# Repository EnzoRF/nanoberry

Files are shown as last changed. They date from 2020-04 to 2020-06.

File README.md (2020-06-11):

# Project Nanoberry*
(*) Provisional name until we find anything better

# What is it?
Nanoberry is a **single-board computer** capable of running **Linux**. It is built around the **i. MX 6 UltraLite** system-on-chip from NXP. It's **open-source hardware**, its design files are made in **KiCad** and it's free for everyone to produce it, sell it, modify it, and sell modified versions of it.

It is designed to be similar to the very popular **Raspberry PI**, with the same board size and connectors located in the same side. There are some differences, most notably it does not have HDMI output.

The goal is to have a small computer that everybody can modify according to their needs. All the electronics components can be purchased from electronics distributors and its operation is well documented by the manufacturers. This is the main difference with Raspberry PI.

All components are also available in industrial grade, for projects that require extra reliabilty with an increase in the cost. 

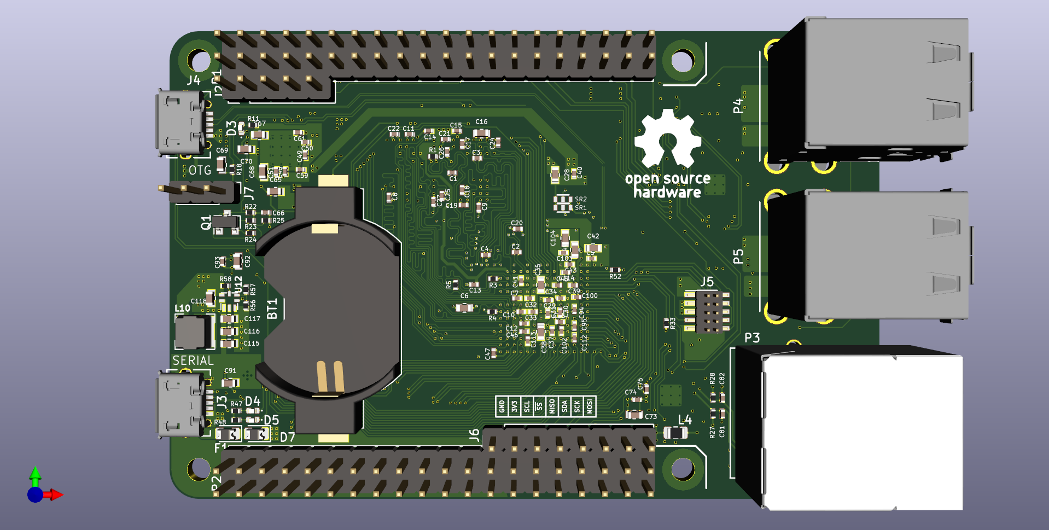
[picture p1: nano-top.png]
3d model front


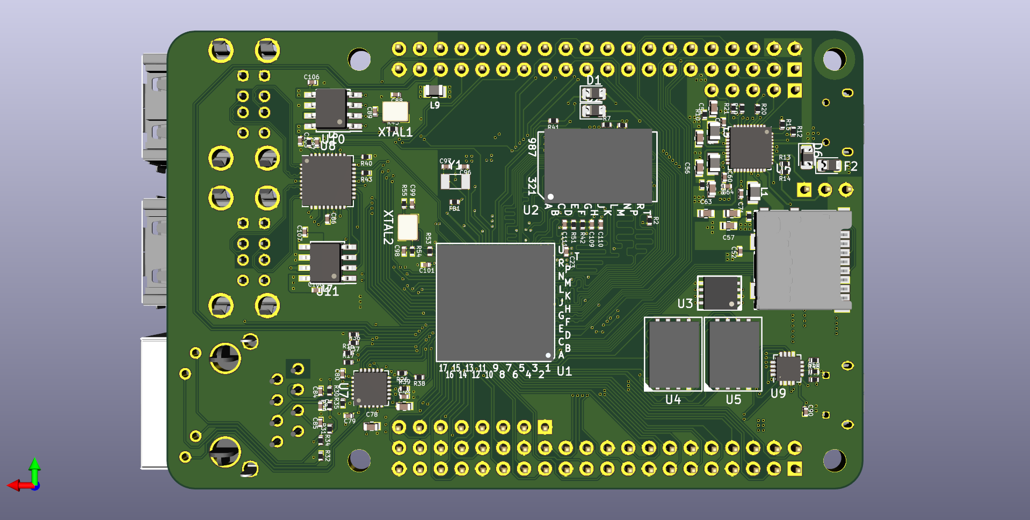
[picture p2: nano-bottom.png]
3d model bottom


## License

You can modify this project and manufacture it, sell it for money, but you have to let me know.

    Nanoberry (provisional name). Open source single board computer.
    Copyright (C) 2020  vpecanins

    This program is free software: you can redistribute it and/or modify
    it under the terms of the GNU General Public License as published by
    the Free Software Foundation, either version 3 of the License, or
    (at your option) any later version.

    This program is distributed in the hope that it will be useful,
    but WITHOUT ANY WARRANTY; without even the implied warranty of
    MERCHANTABILITY or FITNESS FOR A PARTICULAR PURPOSE.  See the
    GNU General Public License for more details.

    You should have received a copy of the GNU General Public License
    along with this program.  If not, see <https://www.gnu.org/licenses/>.

 [GNU GENERAL PUBLIC LICENSE v3](https://www.gnu.org/licenses/gpl-3.0.en.html)

## Specifications

 - System-on-chip NXP i.MX 6 ULL:
	 - ARM Cortex A7 CPU at 900 MHz
	 - Yocto Linux Operating System
 - 4 layer PCB project made in KiCAD
 - Flash memory for program & data storage:
	 - Micro-SD card slot
	 - Onboard QSPI Flash (2 packages) for Bootloader and small OS
 - RAM memory: DDR3L one package
 - Display: 24-bit parallel RGB through bottom connector. (eLCDIF peripheral from i.MX6ULL)
	 - HDMI output would be nice but was discarded due to licensing costs and requirement of NDA does not follow the philosophy of this project.
 - Crypto memory A71CH from NXP to store private/public keys, just for fun because it's cheap.
 - PMIC PF1550 from NXP to generate needed voltages for CPU & memory
 - Ethernet 10/100 one port
 - USB to Serial port bridge for debugging and access Linux console
 - USB OTG port to implement special functions by i.MX (for example Mass Storage Device)
 - 4 port USB HUB to connect keyboard, mouse & other USB devices
 - Battery holder for RTC
 - Many I2C, SPI, I2S, UART, GPIO available through pin headers

## Block Diagram

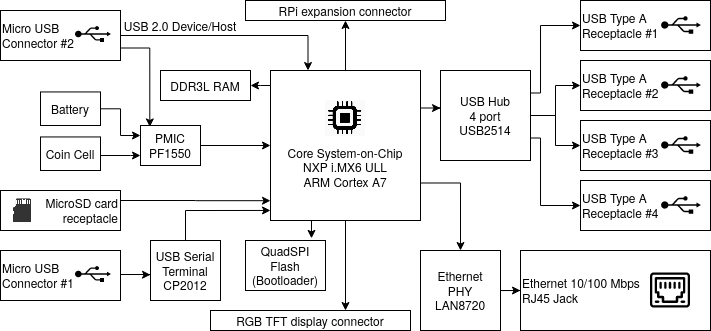
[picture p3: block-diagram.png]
block diagram


## Status of the project

Hardware design is 99% done and has not been tested. We have based the design around a reference design from NXP. The most critical part of the layout, that is DDR3 routing, has been copied straight away from reference design.

Up to now this project has been brought up by a single person. This project cannot succeed without a team of people working on it. We need to check the schematics, refine layout, bring up the first prototype, boot Linux on it. If you are interested let me know.

We are also looking for funding/sponsors. NXP, we are using a lot of your chips here, if you are interested please show up now.

## BOM (critical components)

 1. MCIMX6Y2CVM08AB - System on chip Cortex A9 (NXP)
 2. MC34PF1550A6EP - PMIC (NXP)
 3. W634GU6MB - 512 MByte RAM (Winbond)
 4. CP2102N-A01-GQFN20 (SiLabs)
 5. LAN8720A-CP (Microchip)
 6. USB2514B (Microchip)

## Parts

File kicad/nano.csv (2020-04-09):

Id | Designator | Package | Quantity | Designation | Supplier and ref
1 | R47,R40,R41,R42,R43,R44,R45,R46 | SMD_0402 | 8 | R
2 | R48,R49,R50,R51,R52,R53,R54,R55,R24 | SMD_0402 | 9 | 0
3 | D2 | SR_0402 | 1 | PRTR5V0U2X
4 | P3 | MTJ-88TX1-FSD-D1LH-M4Y | 1 | J0011D01BNL
5 | R28 | SMD_0402 | 1 | 12.1K
6 | R29,R30 | SMD_0402 | 2 | 4.75K
7 | R31 | SMD_0402 | 1 | 1M
8 | R32,R25,R26 | SMD_0402 | 3 | 0R
9 | R27 | SMD_0402 | 1 | 1.5K
10 | C69,C70 | SMD_0402 | 2 | 18p
11 | R33 | SMD_0402 | 1 | 12K 1%
12 | U5 | QFN-36-1EP_6x6mm_P0.5mm_EP3.7x3.7mm | 1 | USB2514B
13 | C66,C63,C44 | SMD_0402 | 3 | 4.7u
14 | C75,C64,C65,C76,C68,C67,C71,C72,C73,C74 | SMD_0402 | 10 | 0.1u
15 | D4,D3,D1 | SMD_0402 | 3 | LED
16 | C77,C62,C78,C29,C30 | SMD_0402 | 5 | CP1
17 | R21,R22,R20,R23 | SMD_0402 | 4 | 49.9 1%
18 | C61,C58,C60,C59 | SMD_0402 | 4 | 10p
19 | C57,C54,C55 | SMD_0402 | 3 | 1u
20 | W1 | TestPoint_Pad_1.0x1.0mm | 1 | ONKEY
21 | L4 | R_0805_2012Metric | 1 | 2.0A/0.050 DCR
22 | W7 | TestPoint_Pad_1.0x1.0mm | 1 | ETH_ADDR0
23 | U7 | SiliconLabs_QFN-20-1EP_3x3mm_P0.5mm_ThermalVias | 1 | CP2102N-QFN20
24 | SR1,SR2,SR4 | SR_0402 | 3 | 0R
25 | U4 | QFN-24-1EP_4x4mm_P0.5mm_EP2.6x2.6mm_ThermalVias | 1 | LAN8720A
26 | C56 | SMD_0402 | 1 | 470p
27 | SR3,SR5 | SR_0402 | 2 | 330R
28 | SR6,SR7,SR8,SR9 | SR_0402 | 4 | 4.75K
29 | W2 | TestPoint_Pad_1.0x1.0mm | 1 | ETH_CLK
30 | W3 | TestPoint_Pad_1.0x1.0mm | 1 | ETH_INT
31 | W4 | TestPoint_Pad_1.0x1.0mm | 1 | ETH_MODE0
32 | W5 | TestPoint_Pad_1.0x1.0mm | 1 | ETH_MODE1
33 | W6 | TestPoint_Pad_1.0x1.0mm | 1 | ETH_MODE2
34 | C1 | SMD_0402 | 1 | 22u 6.3V
35 | C2 | SMD_0402 | 1 | 10u 10V
36 | C3,C4,C5,C6,C7,C8,C9,C10,C11,C12,C13,C14,C15,C16,C17,C18,C19,C20,C21,C26,C27,C28 | SMD_0402 | 22 | 220n 10V
37 | C22,C23 | SMD_0402 | 2 | 2.2p 50V
38 | C24,C25 | SMD_0402 | 2 | 2.2p 50V DNP
39 | C31,C32,C33,C39,C40,C41,C47 | SMD_0402 | 7 | 4.7u 6.3v
40 | C34,C35,C36,C37 | SMD_0402 | 4 | 1.0u 10v
41 | C38 | SMD_0402 | 1 | 0.1u 16v
42 | C42 | SMD_0402 | 1 | 1.0u
43 | C43 | SMD_0402 | 1 | 0.47u
44 | C45,C46,C50,C51,C52,C53 | SMD_0402 | 6 | 10u
45 | C48,C49 | SMD_0402 | 2 | 100u
46 | R1,R5,R13 | SMD_0402 | 3 | 240 1%
47 | R2,R3,R4 | SMD_0402 | 3 | 10K
48 | R6 | SMD_0402 | 1 | 470
49 | R7,R8 | SMD_0402 | 2 | 1.5K DNP
50 | R9 | SMD_0402 | 1 | 47
51 | R10,R11,R12 | SMD_0402 | 3 | 0.02
52 | R14,R17,R18,R19 | SMD_0402 | 4 | 100K
53 | R15,R16 | SMD_0402 | 2 | 4.7K
54 | P1,P2 | PINHD_2X20_X | 2 | CONN_02X20
55 | U1 | IMX6UL_BGA289 | 1 | IMX6UL_BGA289
56 | U2 | DDR3_BGA96 | 1 | DDR3_BGA96
57 | L1,L2,L3 | R_0805_2012Metric | 3 | 1uH
58 | U3 | QFN-40-1EP_5x5mm_P0.4mm_EP3.6x3.6mm | 1 | PF1550
59 | J1 | MCSP-G-08-A-SG-HC | 1 | Conn_01x09_Male
60 | U6 | WSON8_8x6mm | 1 | W25M512JV
61 | XTAL1 | Oscillator_SMD_EuroQuartz_XO32-4Pin_3.2x2.5mm | 1 | 25MHz
62 | XTAL2 | Oscillator_SMD_EuroQuartz_XO32-4Pin_3.2x2.5mm | 1 | 24MHz 50ppm
63 | J3 | ADC-029-X | 1 | DC Jack
64 | J4 | MCR-B-S-RA-SMT-CS5 | 1 | USB_Micro
65 | J5 | MCR-B-S-RA-SMT-CS5 | 1 | USB_OTG
66 | L5,L6,L7,L8 | R_0805_2012Metric | 4 | FB
67 | P4,P5 | USB-A-D-RA-30 | 2 | USB-A-D-RA-30

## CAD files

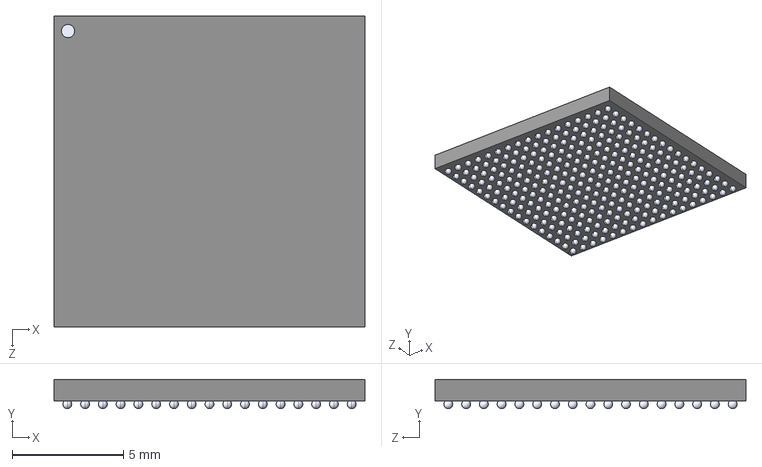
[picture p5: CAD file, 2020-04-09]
kicad/3dmodels/MCIMX6Y0CVM05AB--3DModel-STEP-56544.STEP
14.0 x 1.32 x 14.0 mm

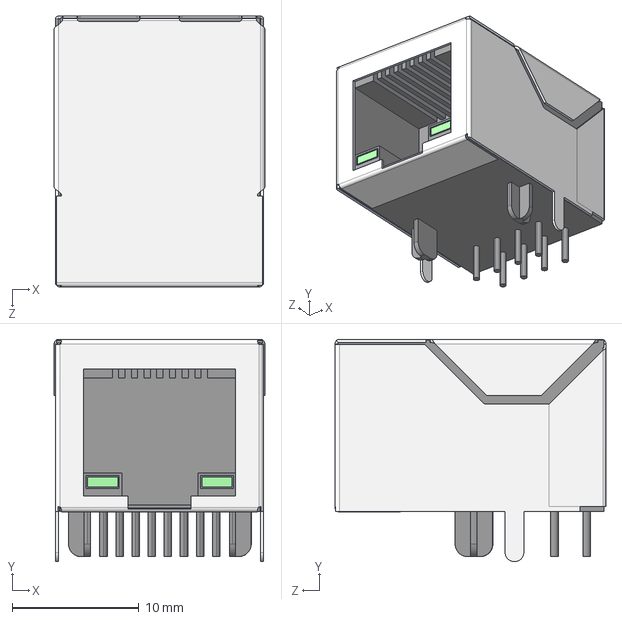
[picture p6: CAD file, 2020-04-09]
kicad/3dmodels/User Library-RJ45-01-J0011D01BNL.STEP
16.6 x 17.5 x 21.3 mm
Shield_1

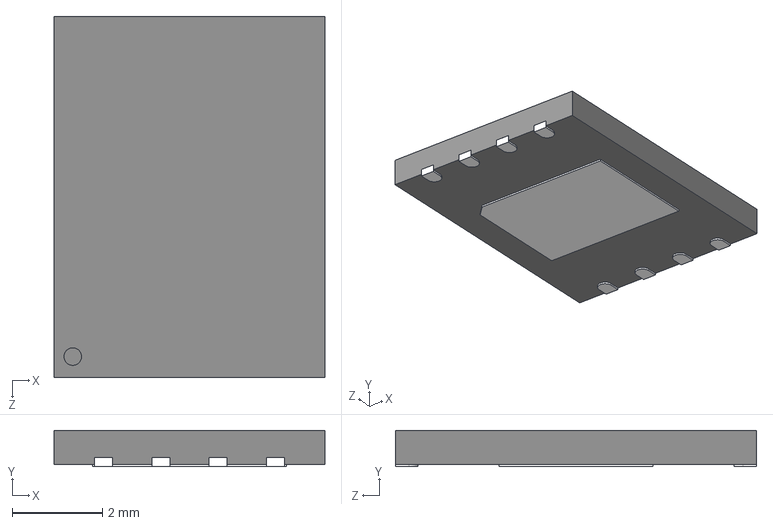
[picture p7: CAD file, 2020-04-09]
kicad/3dmodels/W25Q256JVEIQ TR--3DModel-STEP-1.STEP
6.00 x 0.8 x 8.00 mm

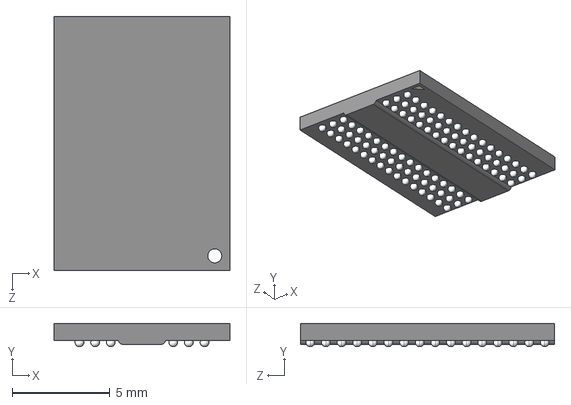
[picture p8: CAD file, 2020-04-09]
kicad/3dmodels/IS46TR16256A-125KBLA2--3DModel-STEP-56544.STEP
9.00 x 1.20 x 13.0 mm

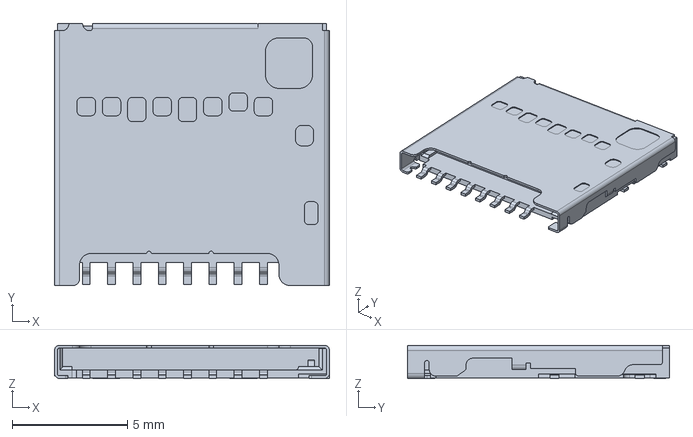
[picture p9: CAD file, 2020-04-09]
kicad/3dmodels/1040310811.stp
11.9 x 11.4 x 1.45 mm

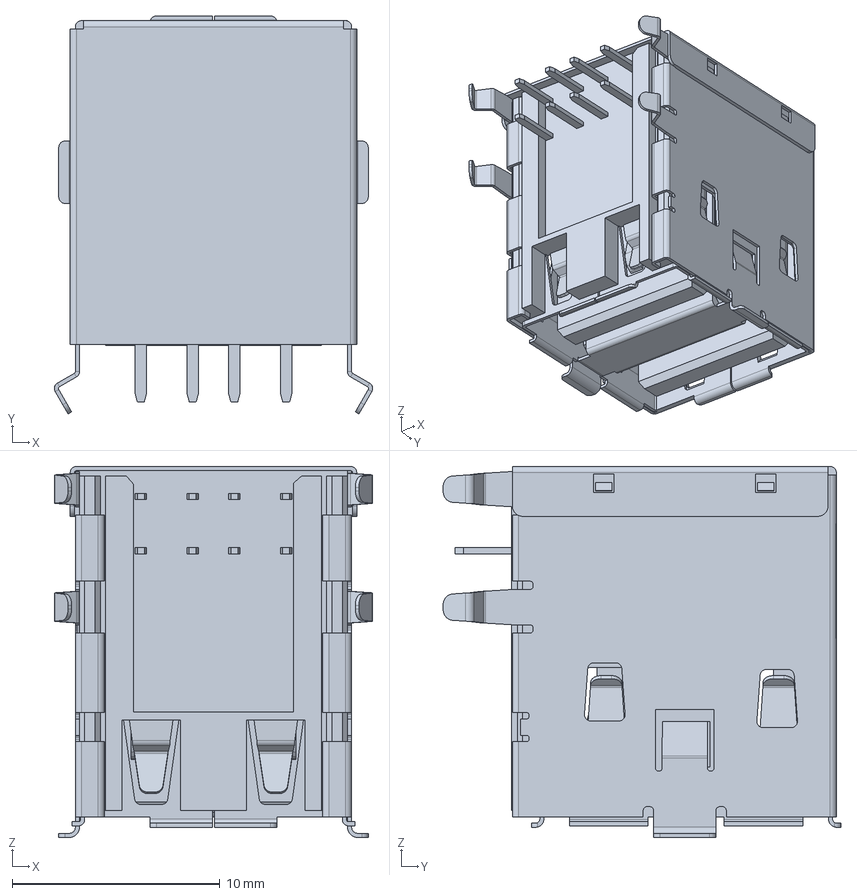
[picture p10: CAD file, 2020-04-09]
kicad/3dmodels/672983090.stp
15.3 x 19.2 x 17.9 mm

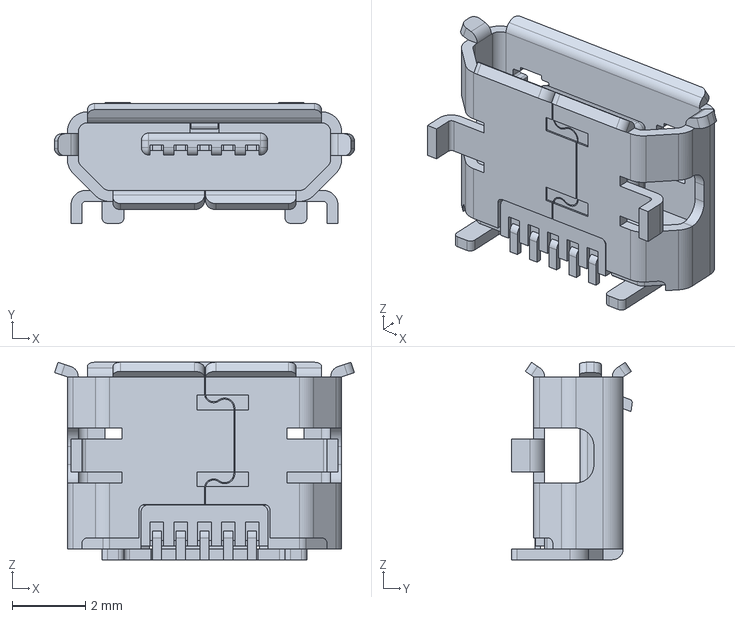
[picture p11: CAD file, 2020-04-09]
kicad/3dmodels/1050170001.stp
8.20 x 3.30 x 5.40 mm

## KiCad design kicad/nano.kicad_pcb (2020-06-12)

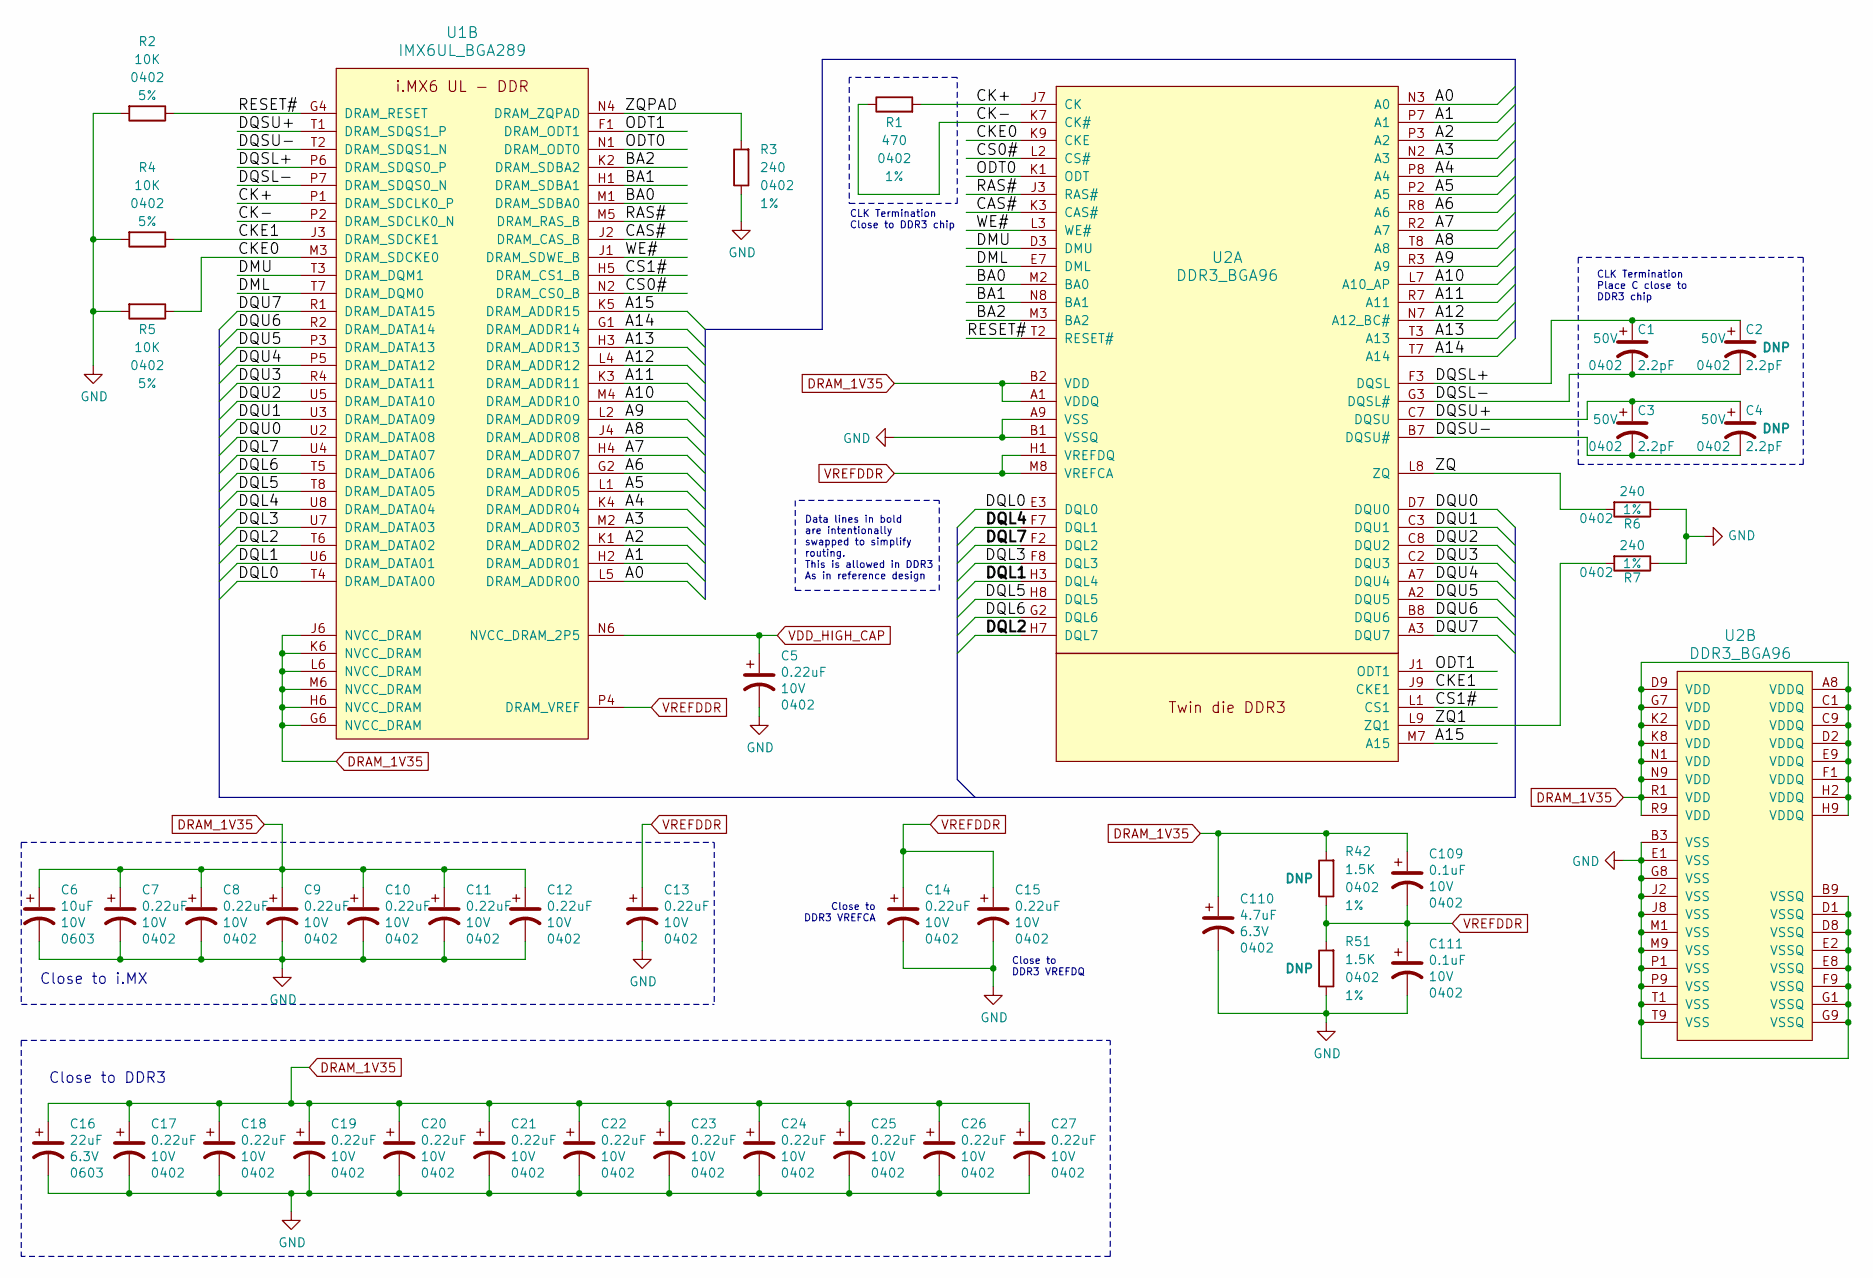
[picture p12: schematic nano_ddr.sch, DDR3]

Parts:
C1, C2, C3, C4: 2.2pF; C_0402_narrow; Voltage 50V
C5, C7, C8, C9, C10, C11, C12, C13, C14, C15, C17, C18, C19, C20, C21, C22, C23, C24, C25, C26, C27: 0.22uF; C_0402_narrow; Voltage 10V
C6: 10uF; C_0603_narrow; Voltage 10V
C16: 22uF; C_0603_narrow; Voltage 6.3V
C109, C111: 0.1uF; C_0402_narrow; Voltage 10V
C110: 4.7uF; C_0402_narrow; Voltage 6.3V
R1: 470; R_0402_narrow; Tolerance 1%
R2, R4, R5: 10K; R_0402_narrow; Tolerance 5%
R3, R6, R7: 240; R_0402_narrow; Tolerance 1%
R42, R51: 1.5K; R_0402_narrow; Tolerance 1%
U1: IMX6UL_BGA289
U2: DDR3_BGA96

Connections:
/DDR/A0: U1.L5 (DRAM_ADDR00), U2.N3 (A0)
/DDR/A1: U1.H2 (DRAM_ADDR01), U2.P7 (A1)
/DDR/A2: U1.K1 (DRAM_ADDR02), U2.P3 (A2)
/DDR/A3: U1.M2 (DRAM_ADDR03), U2.N2 (A3)
/DDR/A4: U1.K4 (DRAM_ADDR04), U2.P8 (A4)
/DDR/A5: U1.L1 (DRAM_ADDR05), U2.P2 (A5)
/DDR/A6: U1.G2 (DRAM_ADDR06), U2.R8 (A6)
/DDR/A7: U1.H4 (DRAM_ADDR07), U2.R2 (A7)
/DDR/A8: U1.J4 (DRAM_ADDR08), U2.T8 (A8)
/DDR/A9: U1.L2 (DRAM_ADDR09), U2.R3 (A9)
/DDR/A10: U1.M4 (DRAM_ADDR10), U2.L7 (A10_AP)
/DDR/A11: U1.K3 (DRAM_ADDR11), U2.R7 (A11)
/DDR/A12: U1.L4 (DRAM_ADDR12), U2.N7 (A12_BC#)
/DDR/A13: U1.H3 (DRAM_ADDR13), U2.T3 (A13)
/DDR/A14: U1.G1 (DRAM_ADDR14), U2.T7 (A14)
/DDR/A15: U1.K5 (DRAM_ADDR15), U2.M7 (A15)
/DDR/BA0: U1.M1 (DRAM_SDBA0), U2.M2 (BA0)
/DDR/BA1: U1.H1 (DRAM_SDBA1), U2.N8 (BA1)
/DDR/BA2: U1.K2 (DRAM_SDBA2), U2.M3 (BA2)
/DDR/CAS#: U1.J2 (DRAM_CAS_B), U2.K3 (CAS#)
/DDR/CK+: R1.2, U1.P1 (DRAM_SDCLK0_P), U2.J7 (CK)
/DDR/CK-: R1.1, U1.P2 (DRAM_SDCLK0_N), U2.K7 (CK#)
/DDR/CKE0: R5.1, U1.M3 (DRAM_SDCKE0), U2.K9 (CKE)
/DDR/CKE1: R4.1, U1.J3 (DRAM_SDCKE1), U2.J9 (CKE1)
/DDR/CS0#: U1.N2 (DRAM_CS0_B), U2.L2 (CS#)
/DDR/CS1#: U1.H5 (DRAM_CS1_B), U2.L1 (CS1)
/DDR/DML: U1.T7 (DRAM_DQM0), U2.E7 (DML)
/DDR/DMU: U1.T3 (DRAM_DQM1), U2.D3 (DMU)
/DDR/DQL0: U1.T4 (DRAM_DATA00), U2.E3 (DQL0)
/DDR/DQL1: U1.U6 (DRAM_DATA01), U2.H3 (DQL4)
/DDR/DQL2: U1.T6 (DRAM_DATA02), U2.H7 (DQL7)
/DDR/DQL3: U1.U7 (DRAM_DATA03), U2.F8 (DQL3)
/DDR/DQL4: U1.U8 (DRAM_DATA04), U2.F7 (DQL1)
/DDR/DQL5: U1.T8 (DRAM_DATA05), U2.H8 (DQL5)
/DDR/DQL6: U1.T5 (DRAM_DATA06), U2.G2 (DQL6)
/DDR/DQL7: U1.U4 (DRAM_DATA07), U2.F2 (DQL2)
/DDR/DQSL+: C1.1, C2.1, U1.P6 (DRAM_SDQS0_P), U2.F3 (DQSL)
/DDR/DQSL-: C1.2, C2.2, U1.P7 (DRAM_SDQS0_N), U2.G3 (DQSL#)
/DDR/DQSU+: C3.1, C4.1, U1.T1 (DRAM_SDQS1_P), U2.C7 (DQSU)
/DDR/DQSU-: C3.2, C4.2, U1.T2 (DRAM_SDQS1_N), U2.B7 (DQSU#)
/DDR/DQU0: U1.U2 (DRAM_DATA08), U2.D7 (DQU0)
/DDR/DQU1: U1.U3 (DRAM_DATA09), U2.C3 (DQU1)
/DDR/DQU2: U1.U5 (DRAM_DATA10), U2.C8 (DQU2)
/DDR/DQU3: U1.R4 (DRAM_DATA11), U2.C2 (DQU3)
/DDR/DQU4: U1.P5 (DRAM_DATA12), U2.A7 (DQU4)
/DDR/DQU5: U1.P3 (DRAM_DATA13), U2.A2 (DQU5)
/DDR/DQU6: U1.R2 (DRAM_DATA14), U2.B8 (DQU6)
/DDR/DQU7: U1.R1 (DRAM_DATA15), U2.A3 (DQU7)
/DDR/ODT0: U1.N1 (DRAM_ODT0), U2.K1 (ODT)
/DDR/ODT1: U1.F1 (DRAM_ODT1), U2.J1 (ODT1)
/DDR/RAS#: U1.M5 (DRAM_RAS_B), U2.J3 (RAS#)
/DDR/RESET#: R2.1, U1.G4 (DRAM_RESET), U2.T2 (RESET#)
/DDR/WE#: U1.J1 (DRAM_SDWE_B), U2.L3 (WE#)
/DDR/ZQ: R6.2, U2.L8 (ZQ)
/DDR/ZQ1: R7.2, U2.L9 (ZQ1)
/DDR/ZQPAD: R3.2, U1.N4 (DRAM_ZQPAD)
DRAM_1V35: C6.1, C7.1, C8.1, C9.1, C10.1, C11.1, C12.1, C16.1, C17.1, C18.1, C19.1, C20.1, C21.1, C22.1, C23.1, C24.1, C25.1, C26.1, C27.1, C109.1, C110.1, R42.2, U1.G6 (NVCC_DRAM), U1.H6 (NVCC_DRAM), U1.J6 (NVCC_DRAM), U1.K6 (NVCC_DRAM), U1.L6 (NVCC_DRAM), U1.M6 (NVCC_DRAM), U2.A1 (VDDQ), U2.A8 (VDDQ), U2.B2 (VDD), U2.C1 (VDDQ), U2.C9 (VDDQ), U2.D2 (VDDQ), U2.D9 (VDD), U2.E9 (VDDQ), U2.F1 (VDDQ), U2.G7 (VDD), U2.H2 (VDDQ), U2.H9 (VDDQ), U2.K2 (VDD), U2.K8 (VDD), U2.N1 (VDD), U2.N9 (VDD), U2.R1 (VDD), U2.R9 (VDD); also elsewhere on the board
GND: C5.2, C6.2, C7.2, C8.2, C9.2, C10.2, C11.2, C12.2, C13.2, C14.2, C15.2, C16.2, C17.2, C18.2, C19.2, C20.2, C21.2, C22.2, C23.2, C24.2, C25.2, C26.2, C27.2, C110.2, C111.2, R2.2, R3.1, R4.2, R5.2, R6.1, R7.1, R51.1, U2.A9 (VSS), U2.B1 (VSSQ), U2.B3 (VSS), U2.B9 (VSSQ), U2.D1 (VSSQ), U2.D8 (VSSQ), U2.E1 (VSS), U2.E2 (VSSQ), U2.E8 (VSSQ), U2.F9 (VSSQ), U2.G1 (VSSQ), U2.G8 (VSS), U2.G9 (VSSQ), U2.J2 (VSS), U2.J8 (VSS), U2.M1 (VSS), U2.M9 (VSS), U2.P1 (VSS), U2.P9 (VSS), U2.T1 (VSS), U2.T9 (VSS); also elsewhere on the board
VDD_HIGH_CAP: C5.1, U1.N6 (NVCC_DRAM_2P5); also elsewhere on the board
VREFDDR: C13.1, C14.1, C15.1, C109.2, C111.1, R42.1, R51.2, U1.P4 (DRAM_VREF), U2.H1 (VREFDQ), U2.M8 (VREFCA); also elsewhere on the board

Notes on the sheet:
CLK Termination Close to DDR3 chip
CLK Termination Place C close to DDR3 chip
Close to i.MX
Close to DDR3
Close to DDR3 VREFCA
Data lines in bold are intentionally swapped to simplify routing. This is allowed in DDR3 As in reference design
Close to DDR3 VREFDQ

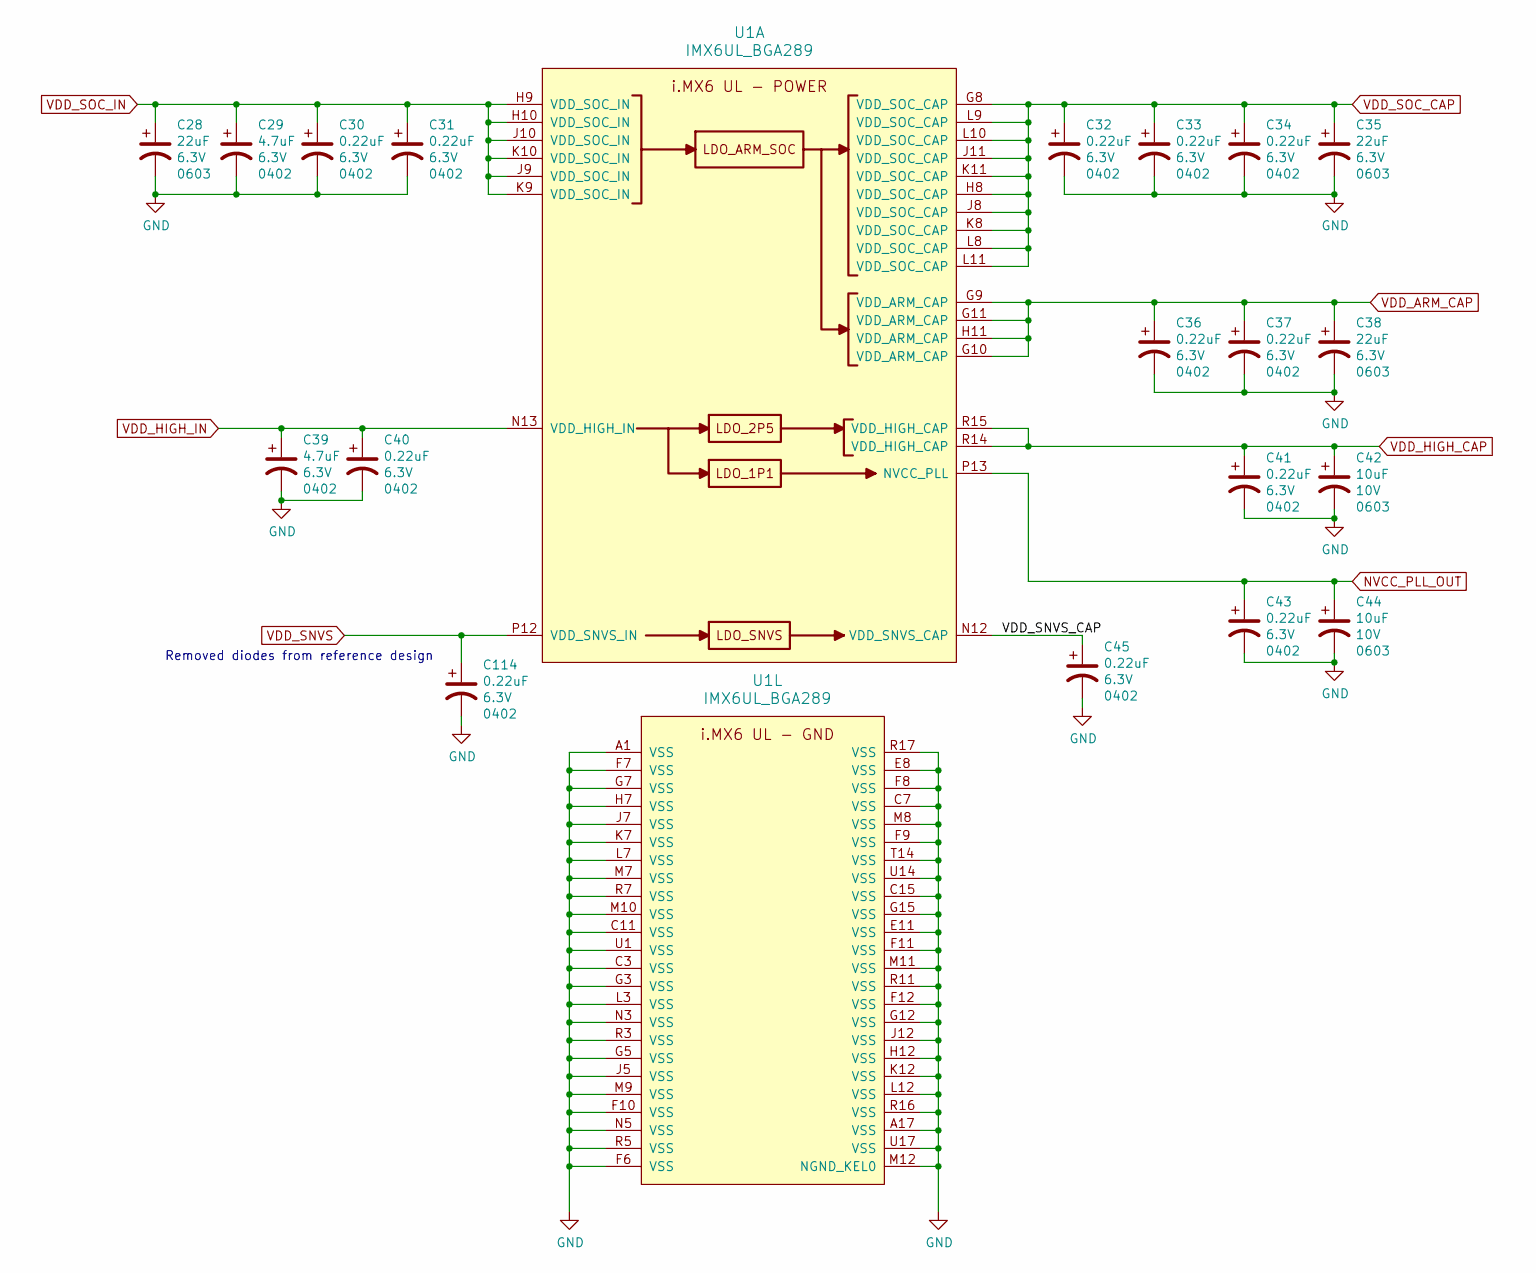
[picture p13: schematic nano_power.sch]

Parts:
C28, C35, C38: 22uF; C_0603_narrow; Voltage 6.3V
C29, C39: 4.7uF; C_0402_narrow; Voltage 6.3V
C30, C31, C32, C33, C34, C36, C37, C40, C41, C43, C45, C114: 0.22uF; C_0402_narrow; Voltage 6.3V
C42, C44: 10uF; C_0603_narrow; Voltage 10V
U1: IMX6UL_BGA289

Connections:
/IMX_Power_Pins/VDD_SNVS_CAP: C45.1, U1.N12 (VDD_SNVS_CAP)
GND: C28.2, C29.2, C30.2, C31.2, C32.2, C33.2, C34.2, C35.2, C36.2, C37.2, C38.2, C39.2, C40.2, C41.2, C42.2, C43.2, C44.2, C45.2, C114.2, U1.A1 (VSS), U1.A17 (VSS), U1.C3 (VSS), U1.C7 (VSS), U1.C11 (VSS), U1.C15 (VSS), U1.E8 (VSS), U1.E11 (VSS), U1.F6 (VSS), U1.F7 (VSS), U1.F8 (VSS), U1.F9 (VSS), U1.F10 (VSS), U1.F11 (VSS), U1.F12 (VSS), U1.G3 (VSS), U1.G5 (VSS), U1.G7 (VSS), U1.G12 (VSS), U1.G15 (VSS), U1.H7 (VSS), U1.H12 (VSS), U1.J5 (VSS), U1.J7 (VSS), U1.J12 (VSS), U1.K7 (VSS), U1.K12 (VSS), U1.L3 (VSS), U1.L7 (VSS), U1.L12 (VSS), U1.M7 (VSS), U1.M8 (VSS), U1.M9 (VSS), U1.M10 (VSS), U1.M11 (VSS), U1.M12 (NGND_KEL0), U1.N3 (VSS), U1.N5 (VSS), U1.R3 (VSS), U1.R5 (VSS), U1.R7 (VSS), U1.R11 (VSS), U1.R16 (VSS), U1.R17 (VSS), U1.T14 (VSS), U1.U1 (VSS), U1.U14 (VSS), U1.U17 (VSS); also elsewhere on the board
NVCC_PLL_OUT: C43.1, C44.1, U1.P13 (NVCC_PLL)
VDD_ARM_CAP: C36.1, C37.1, C38.1, U1.G9 (VDD_ARM_CAP), U1.G10 (VDD_ARM_CAP), U1.G11 (VDD_ARM_CAP), U1.H11 (VDD_ARM_CAP)
VDD_HIGH_CAP: C41.1, C42.1, U1.R14 (VDD_HIGH_CAP), U1.R15 (VDD_HIGH_CAP); also elsewhere on the board
VDD_HIGH_IN: C39.1, C40.1, U1.N13 (VDD_HIGH_IN); also elsewhere on the board
VDD_SNVS: C114.1, U1.P12 (VDD_SNVS_IN); also elsewhere on the board
VDD_SOC_CAP: C32.1, C33.1, C34.1, C35.1, U1.G8 (VDD_SOC_CAP), U1.H8 (VDD_SOC_CAP), U1.J8 (VDD_SOC_CAP), U1.J11 (VDD_SOC_CAP), U1.K8 (VDD_SOC_CAP), U1.K11 (VDD_SOC_CAP), U1.L8 (VDD_SOC_CAP), U1.L9 (VDD_SOC_CAP), U1.L10 (VDD_SOC_CAP), U1.L11 (VDD_SOC_CAP)
VDD_SOC_IN: C28.1, C29.1, C30.1, C31.1, U1.H9 (VDD_SOC_IN), U1.H10 (VDD_SOC_IN), U1.J9 (VDD_SOC_IN), U1.J10 (VDD_SOC_IN), U1.K9 (VDD_SOC_IN), U1.K10 (VDD_SOC_IN); also elsewhere on the board

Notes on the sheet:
Removed diodes from reference design

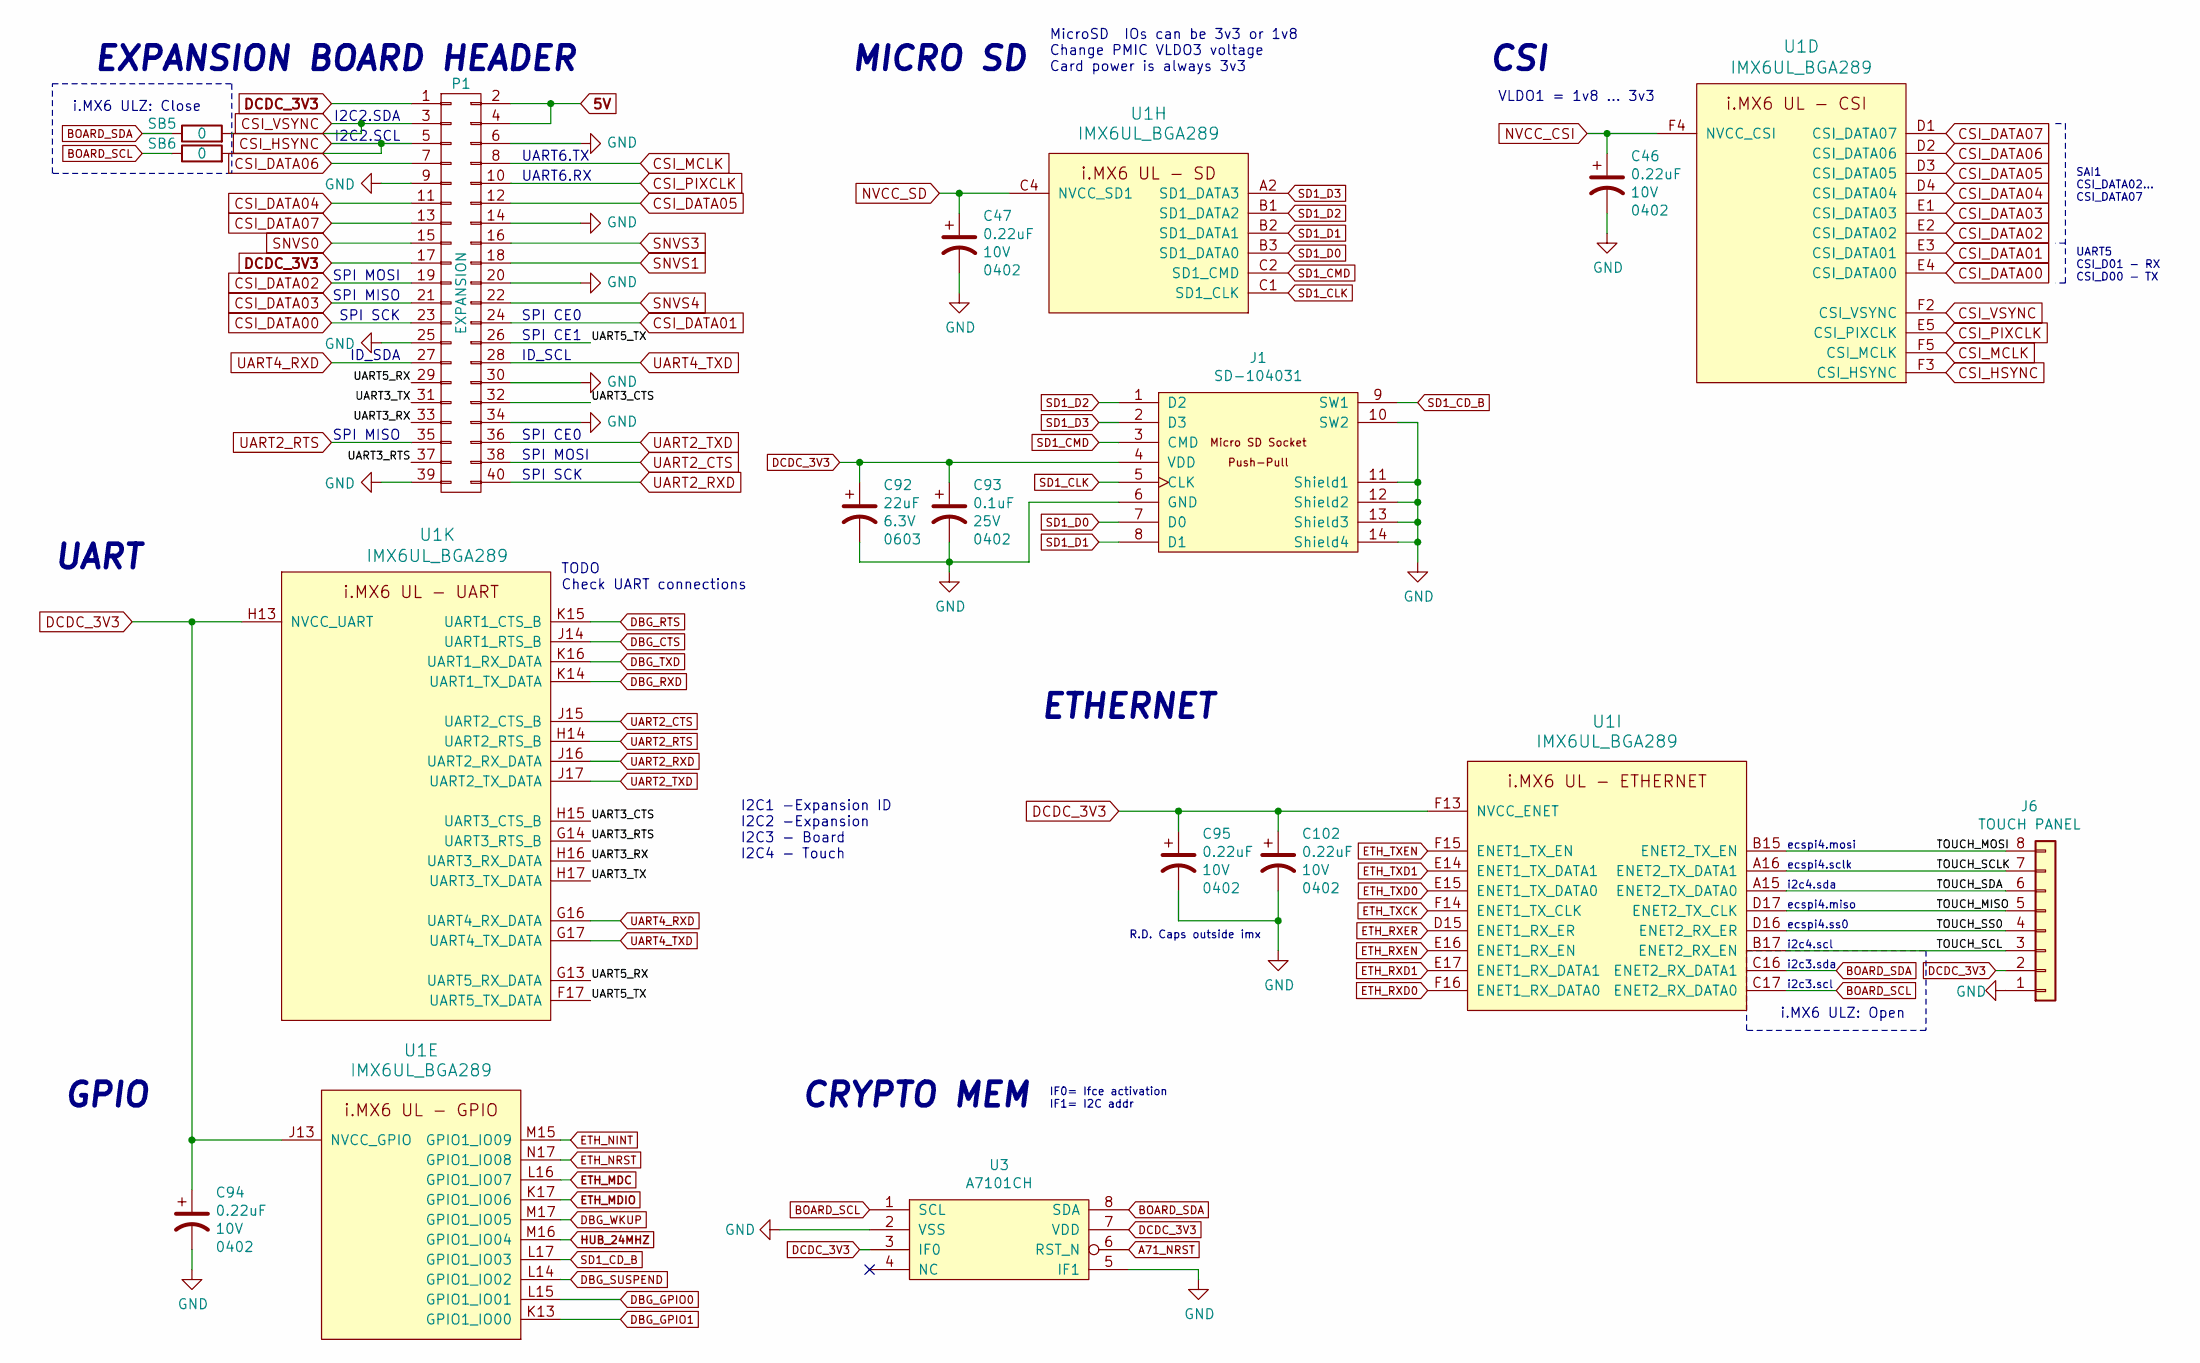
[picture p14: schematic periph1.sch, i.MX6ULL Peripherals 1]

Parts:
C46, C47, C94, C95, C102: 0.22uF; C_0402_narrow; Voltage 10V
C92: 22uF; C_0603_narrow; Voltage 6.3V
C93: 0.1uF; C_0402_narrow; Voltage 25V
J1: SD-104031; uSD_104031
J6: TOUCH PANEL; PinHeader_1x08_P2.54mm_Vertical
P1: EXPANSION; PINHD_2X20_X
SB5, SB6: 0; R_0402_narrow; Tolerance ?
U1: IMX6UL_BGA289
U3: A7101CH; SOT909-1

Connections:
5V: P1.2, P1.4; also elsewhere on the board
/IMX_Peripherals_1/TOUCH_MISO: J6.5, U1.D17 (ENET2_TX_CLK)
/IMX_Peripherals_1/TOUCH_MOSI: J6.8, U1.B15 (ENET2_TX_EN)
/IMX_Peripherals_1/TOUCH_SCL: J6.3, U1.B17 (ENET2_RX_EN)
/IMX_Peripherals_1/TOUCH_SCLK: J6.7, U1.A16 (ENET2_TX_DATA1)
/IMX_Peripherals_1/TOUCH_SDA: J6.6, U1.A15 (ENET2_TX_DATA0)
/IMX_Peripherals_1/TOUCH_SS0: J6.4, U1.D16 (ENET2_RX_ER)
/IMX_Peripherals_1/UART3_CTS: P1.32, U1.H15 (UART3_CTS_B)
/IMX_Peripherals_1/UART3_RTS: P1.37, U1.G14 (UART3_RTS_B)
/IMX_Peripherals_1/UART3_RX: P1.33, U1.H16 (UART3_RX_DATA)
/IMX_Peripherals_1/UART3_TX: P1.31, U1.H17 (UART3_TX_DATA)
/IMX_Peripherals_1/UART5_RX: P1.29, U1.G13 (UART5_RX_DATA)
/IMX_Peripherals_1/UART5_TX: P1.26, U1.F17 (UART5_TX_DATA)
A71_NRST: U3.6 (RST_N); also elsewhere on the board
BOARD_SCL: SB6.1, U1.C17 (ENET2_RX_DATA0), U3.1 (SCL); also elsewhere on the board
BOARD_SDA: SB5.1, U1.C16 (ENET2_RX_DATA1), U3.8 (SDA); also elsewhere on the board
CSI_DATA00: P1.23, U1.E4 (CSI_DATA00)
CSI_DATA01: P1.24, U1.E3 (CSI_DATA01)
CSI_DATA02: P1.19, U1.E2 (CSI_DATA02)
CSI_DATA03: P1.21, U1.E1 (CSI_DATA03)
CSI_DATA04: P1.11, U1.D4 (CSI_DATA04)
CSI_DATA05: P1.12, U1.D3 (CSI_DATA05)
CSI_DATA06: P1.7, U1.D2 (CSI_DATA06)
CSI_DATA07: P1.13, U1.D1 (CSI_DATA07)
CSI_HSYNC: P1.5, SB6.2, U1.F3 (CSI_HSYNC)
CSI_MCLK: P1.8, U1.F5 (CSI_MCLK)
CSI_PIXCLK: P1.10, U1.E5 (CSI_PIXCLK)
CSI_VSYNC: P1.3, SB5.2, U1.F2 (CSI_VSYNC)
DBG_CTS: U1.J14 (UART1_RTS_B); also elsewhere on the board
DBG_GPIO0: U1.L15 (GPIO1_IO01); also elsewhere on the board
DBG_GPIO1: U1.K13 (GPIO1_IO00); also elsewhere on the board
DBG_RTS: U1.K15 (UART1_CTS_B); also elsewhere on the board
DBG_RXD: U1.K14 (UART1_TX_DATA); also elsewhere on the board
DBG_SUSPEND: U1.L14 (GPIO1_IO02); also elsewhere on the board
DBG_TXD: U1.K16 (UART1_RX_DATA); also elsewhere on the board
DBG_WKUP: U1.M17 (GPIO1_IO05); also elsewhere on the board
DCDC_3V3: C92.1, C93.1, C94.1, C95.1, C102.1, J1.4 (VDD), J6.2, P1.1, P1.17, U1.F13 (NVCC_ENET), U1.H13 (NVCC_UART), U1.J13 (NVCC_GPIO), U3.3 (IF0), U3.7 (VDD); also elsewhere on the board
ETH_MDC: U1.L16 (GPIO1_IO07); also elsewhere on the board
ETH_MDIO: U1.K17 (GPIO1_IO06); also elsewhere on the board
ETH_NINT: U1.M15 (GPIO1_IO09); also elsewhere on the board
ETH_NRST: U1.N17 (GPIO1_IO08); also elsewhere on the board
ETH_RXD0: U1.F16 (ENET1_RX_DATA0); also elsewhere on the board
ETH_RXD1: U1.E17 (ENET1_RX_DATA1); also elsewhere on the board
ETH_RXEN: U1.E16 (ENET1_RX_EN); also elsewhere on the board
ETH_RXER: U1.D15 (ENET1_RX_ER); also elsewhere on the board
ETH_TXCK: U1.F14 (ENET1_TX_CLK); also elsewhere on the board
ETH_TXD0: U1.E15 (ENET1_TX_DATA0); also elsewhere on the board
ETH_TXD1: U1.E14 (ENET1_TX_DATA1); also elsewhere on the board
ETH_TXEN: U1.F15 (ENET1_TX_EN); also elsewhere on the board
GND: C46.2, C47.2, C92.2, C93.2, C94.2, C95.2, C102.2, J1.6 (GND), J1.10 (SW2), J1.11 (Shield1), J1.12 (Shield2), J1.13 (Shield3), J1.14 (Shield4), J6.1, P1.6, P1.9, P1.14, P1.20, P1.25, P1.30, P1.34, P1.39, U3.2 (VSS), U3.5 (IF1); also elsewhere on the board
HUB_24MHZ: U1.M16 (GPIO1_IO04); also elsewhere on the board
NVCC_CSI: C46.1, U1.F4 (NVCC_CSI); also elsewhere on the board
NVCC_SD: C47.1, U1.C4 (NVCC_SD1); also elsewhere on the board
SD1_CD_B: J1.9 (SW1), U1.L17 (GPIO1_IO03)
SD1_CLK: J1.5 (CLK), U1.C1 (SD1_CLK)
SD1_CMD: J1.3 (CMD), U1.C2 (SD1_CMD)
SD1_D0: J1.7 (D0), U1.B3 (SD1_DATA0)
SD1_D1: J1.8 (D1), U1.B2 (SD1_DATA1)
SD1_D2: J1.1 (D2), U1.B1 (SD1_DATA2)
SD1_D3: J1.2 (D3), U1.A2 (SD1_DATA3)
SNVS0: P1.15; also elsewhere on the board
SNVS1: P1.18; also elsewhere on the board
SNVS3: P1.16; also elsewhere on the board
SNVS4: P1.22; also elsewhere on the board
UART2_CTS: P1.38, U1.J15 (UART2_CTS_B)
UART2_RTS: P1.35, U1.H14 (UART2_RTS_B)
UART2_RXD: P1.40, U1.J16 (UART2_RX_DATA)
UART2_TXD: P1.36, U1.J17 (UART2_TX_DATA)
UART4_RXD: P1.27, U1.G16 (UART4_RX_DATA)
UART4_TXD: P1.28, U1.G17 (UART4_TX_DATA)

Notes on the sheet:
TODO Check UART connections
ETHERNET
UART
EXPANSION BOARD HEADER
MICRO SD
I2C2.SDA
I2C2.SCL
UART6.TX
UART6.RX
SPI MOSI
SPI MISO
SPI SCK
SPI CE0
SPI CE1
ID_SDA
ID_SCL
CSI
CRYPTO MEM
GPIO
MicroSD IOs can be 3v3 or 1v8 Change PMIC VLDO3 voltage Card power is always 3v3
SAI1 CSI_DATA02... CSI_DATA07
UART5 CSI_D01 - RX CSI_D00 - TX
VLDO1 = 1v8 ... 3v3
IF0= Ifce activation IF1= I2C addr
i2c4.sda
i2c4.scl
i2c3.sda
i2c3.scl
I2C1 -Expansion ID I2C2 -Expansion I2C3 - Board I2C4 - Touch
ecspi4.mosi
ecspi4.sclk
ecspi4.miso
ecspi4.ss0
R.D. Caps outside imx
i.MX6 ULZ: Close
i.MX6 ULZ: Open

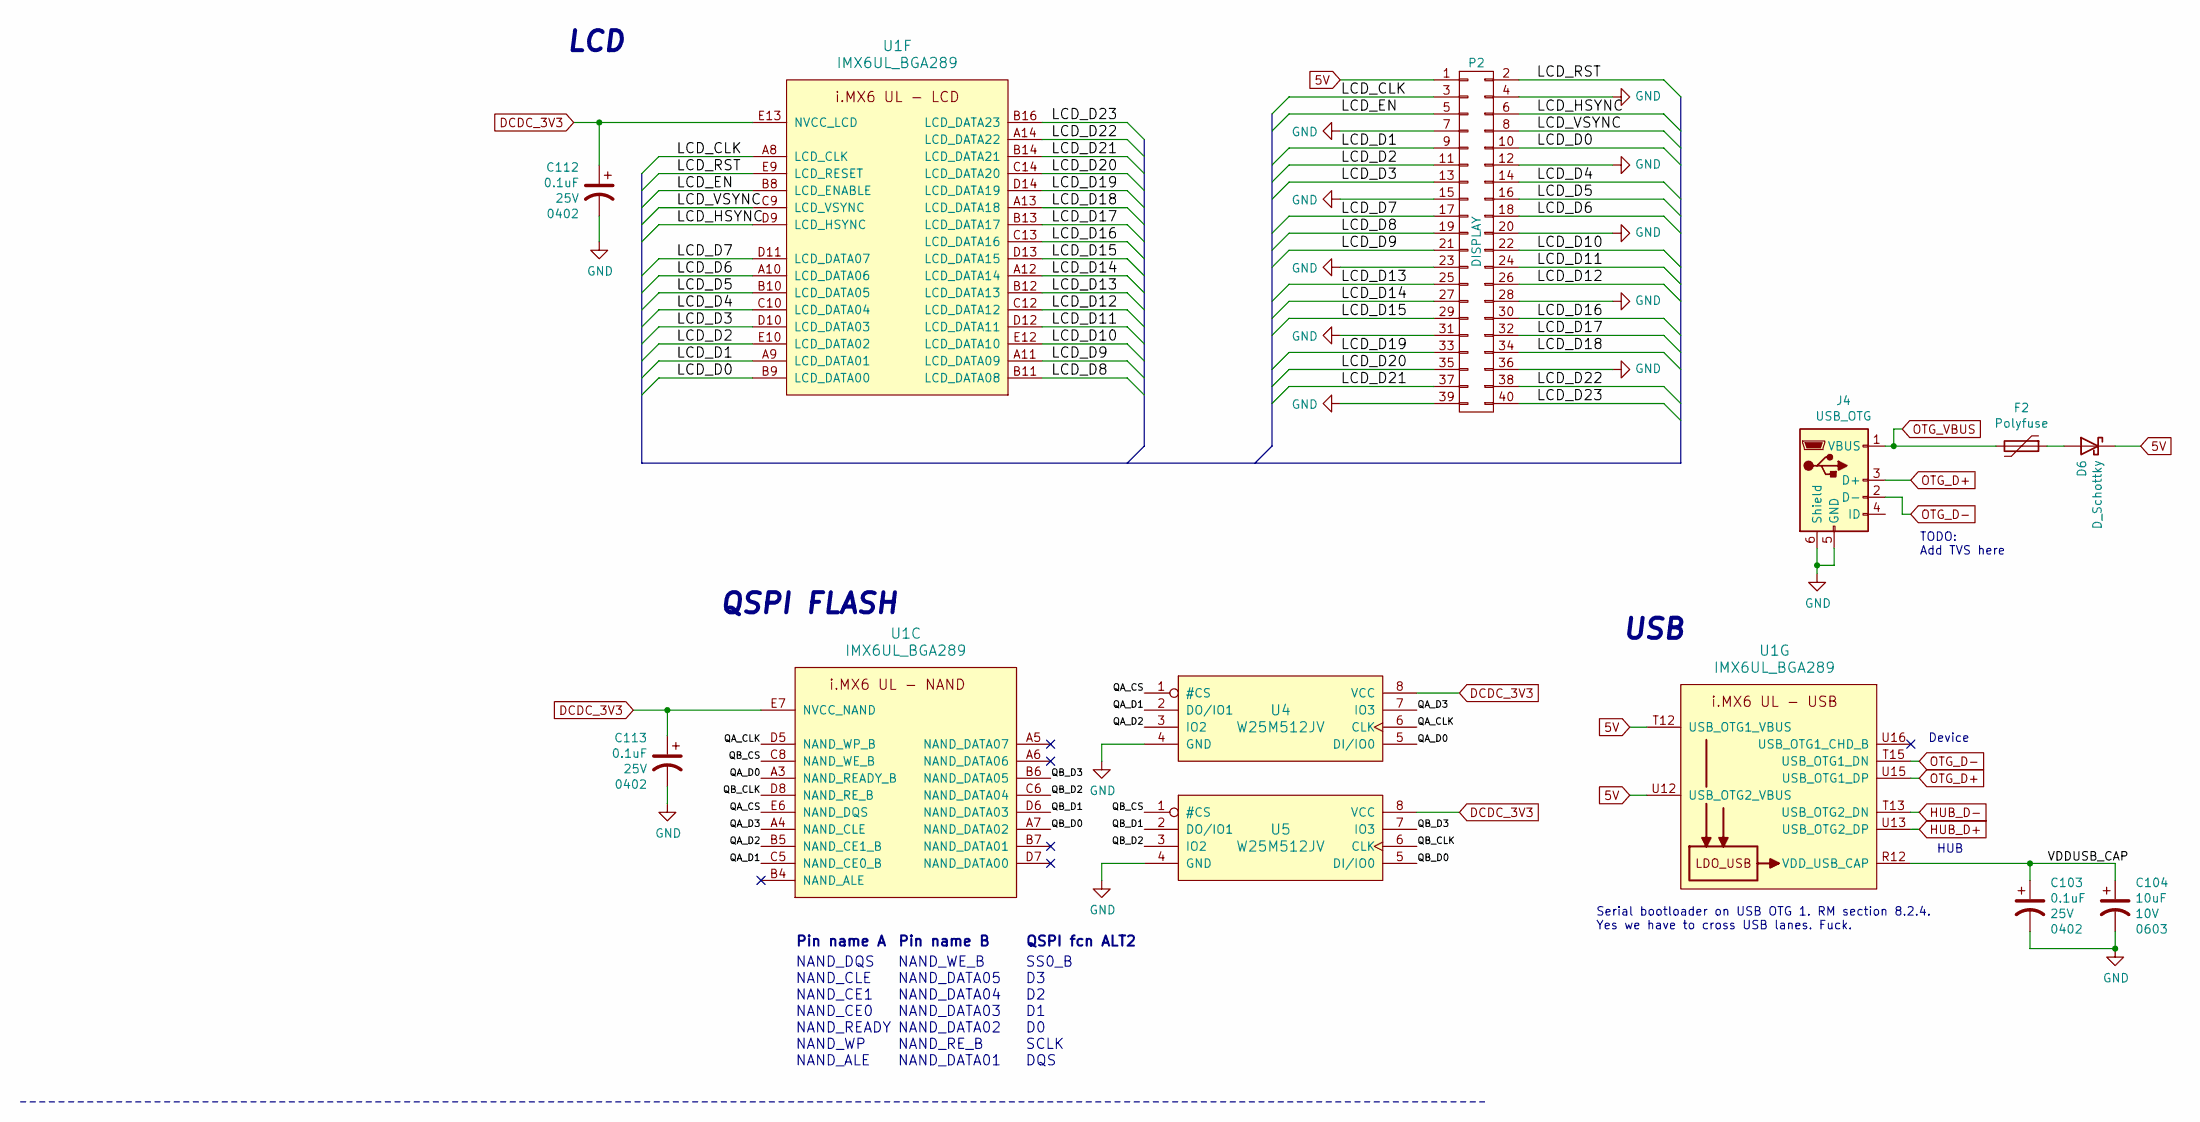
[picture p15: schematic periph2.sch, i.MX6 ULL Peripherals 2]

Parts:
C103, C112, C113: 0.1uF; C_0402_narrow; Voltage 25V
C104: 10uF; C_0603_narrow; Voltage 10V
D6: D_Schottky; D_0805_2012Metric
F2: Polyfuse; D_0805_2012Metric
J4: USB_OTG; MCR-B-S-RA-SMT-CS5
P2: DISPLAY; PINHD_2X20_X
U1: IMX6UL_BGA289
U4, U5: W25M512JV; WSON8_8x6mm

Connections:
5V: D6.1 (K), P2.1, U1.T12 (USB_OTG1_VBUS), U1.U12 (USB_OTG2_VBUS); also elsewhere on the board
/IMX_Peripherals_2/LCD_CLK: P2.3, U1.A8 (LCD_CLK)
/IMX_Peripherals_2/LCD_D0: P2.10, U1.B9 (LCD_DATA00)
/IMX_Peripherals_2/LCD_D1: P2.9, U1.A9 (LCD_DATA01)
/IMX_Peripherals_2/LCD_D2: P2.11, U1.E10 (LCD_DATA02)
/IMX_Peripherals_2/LCD_D3: P2.13, U1.D10 (LCD_DATA03)
/IMX_Peripherals_2/LCD_D4: P2.14, U1.C10 (LCD_DATA04)
/IMX_Peripherals_2/LCD_D5: P2.16, U1.B10 (LCD_DATA05)
/IMX_Peripherals_2/LCD_D6: P2.18, U1.A10 (LCD_DATA06)
/IMX_Peripherals_2/LCD_D7: P2.17, U1.D11 (LCD_DATA07)
/IMX_Peripherals_2/LCD_D8: P2.19, U1.B11 (LCD_DATA08)
/IMX_Peripherals_2/LCD_D9: P2.21, U1.A11 (LCD_DATA09)
/IMX_Peripherals_2/LCD_D10: P2.22, U1.E12 (LCD_DATA10)
/IMX_Peripherals_2/LCD_D11: P2.24, U1.D12 (LCD_DATA11)
/IMX_Peripherals_2/LCD_D12: P2.26, U1.C12 (LCD_DATA12)
/IMX_Peripherals_2/LCD_D13: P2.25, U1.B12 (LCD_DATA13)
/IMX_Peripherals_2/LCD_D14: P2.27, U1.A12 (LCD_DATA14)
/IMX_Peripherals_2/LCD_D15: P2.29, U1.D13 (LCD_DATA15)
/IMX_Peripherals_2/LCD_D16: P2.30, U1.C13 (LCD_DATA16)
/IMX_Peripherals_2/LCD_D17: P2.32, U1.B13 (LCD_DATA17)
/IMX_Peripherals_2/LCD_D18: P2.34, U1.A13 (LCD_DATA18)
/IMX_Peripherals_2/LCD_D19: P2.33, U1.D14 (LCD_DATA19)
/IMX_Peripherals_2/LCD_D20: P2.35, U1.C14 (LCD_DATA20)
/IMX_Peripherals_2/LCD_D21: P2.37, U1.B14 (LCD_DATA21)
/IMX_Peripherals_2/LCD_D22: P2.38, U1.A14 (LCD_DATA22)
/IMX_Peripherals_2/LCD_D23: P2.40, U1.B16 (LCD_DATA23)
/IMX_Peripherals_2/LCD_EN: P2.5, U1.B8 (LCD_ENABLE)
/IMX_Peripherals_2/LCD_HSYNC: P2.6, U1.D9 (LCD_HSYNC)
/IMX_Peripherals_2/LCD_RST: P2.2, U1.E9 (LCD_RESET)
/IMX_Peripherals_2/LCD_VSYNC: P2.8, U1.C9 (LCD_VSYNC)
/IMX_Peripherals_2/QA_CLK: U1.D5 (NAND_WP_B), U4.6 (CLK)
/IMX_Peripherals_2/QA_CS: U1.E6 (NAND_DQS), U4.1 (#CS)
/IMX_Peripherals_2/QA_D0: U1.A3 (NAND_READY_B), U4.5 (DI/IO0)
/IMX_Peripherals_2/QA_D1: U1.C5 (NAND_CE0_B), U4.2 (DO/IO1)
/IMX_Peripherals_2/QA_D2: U1.B5 (NAND_CE1_B), U4.3 (IO2)
/IMX_Peripherals_2/QA_D3: U1.A4 (NAND_CLE), U4.7 (IO3)
/IMX_Peripherals_2/QB_CLK: U1.D8 (NAND_RE_B), U5.6 (CLK)
/IMX_Peripherals_2/QB_CS: U1.C8 (NAND_WE_B), U5.1 (#CS)
/IMX_Peripherals_2/QB_D0: U1.A7 (NAND_DATA02), U5.5 (DI/IO0)
/IMX_Peripherals_2/QB_D1: U1.D6 (NAND_DATA03), U5.2 (DO/IO1)
/IMX_Peripherals_2/QB_D2: U1.C6 (NAND_DATA04), U5.3 (IO2)
/IMX_Peripherals_2/QB_D3: U1.B6 (NAND_DATA05), U5.7 (IO3)
/IMX_Peripherals_2/VDDUSB_CAP: C103.1, C104.1, U1.R12 (VDD_USB_CAP)
DCDC_3V3: C112.1, C113.1, U1.E7 (NVCC_NAND), U1.E13 (NVCC_LCD), U4.8 (VCC), U5.8 (VCC); also elsewhere on the board
GND: C103.2, C104.2, C112.2, C113.2, J4.5 (GND), J4.6 (Shield), P2.4, P2.7, P2.12, P2.15, P2.20, P2.23, P2.28, P2.31, P2.36, P2.39, U4.4 (GND), U5.4 (GND); also elsewhere on the board
HUB_D+: U1.U13 (USB_OTG2_DP); also elsewhere on the board
HUB_D-: U1.T13 (USB_OTG2_DN); also elsewhere on the board
unnamed: D6.2 (A), F2.1
OTG_D+: J4.3 (D+), U1.U15 (USB_OTG1_DP)
OTG_D-: J4.2 (D-), U1.T15 (USB_OTG1_DN)
OTG_VBUS: F2.2, J4.1 (VBUS)

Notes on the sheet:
NAND_DQS NAND_CLE NAND_CE1 NAND_CE0 NAND_READY NAND_WP NAND_ALE
SS0_B D3 D2 D1 D0 SCLK DQS
Pin name A
QSPI fcn ALT2
QSPI FLASH
Pin name B
NAND_WE_B NAND_DATA05 NAND_DATA04 NAND_DATA03 NAND_DATA02 NAND_RE_B NAND_DATA01
USB
HUB
Device
Serial bootloader on USB OTG 1. RM section 8.2.4. Yes we have to cross USB lanes. Fuck.
LCD
TODO: Add TVS here

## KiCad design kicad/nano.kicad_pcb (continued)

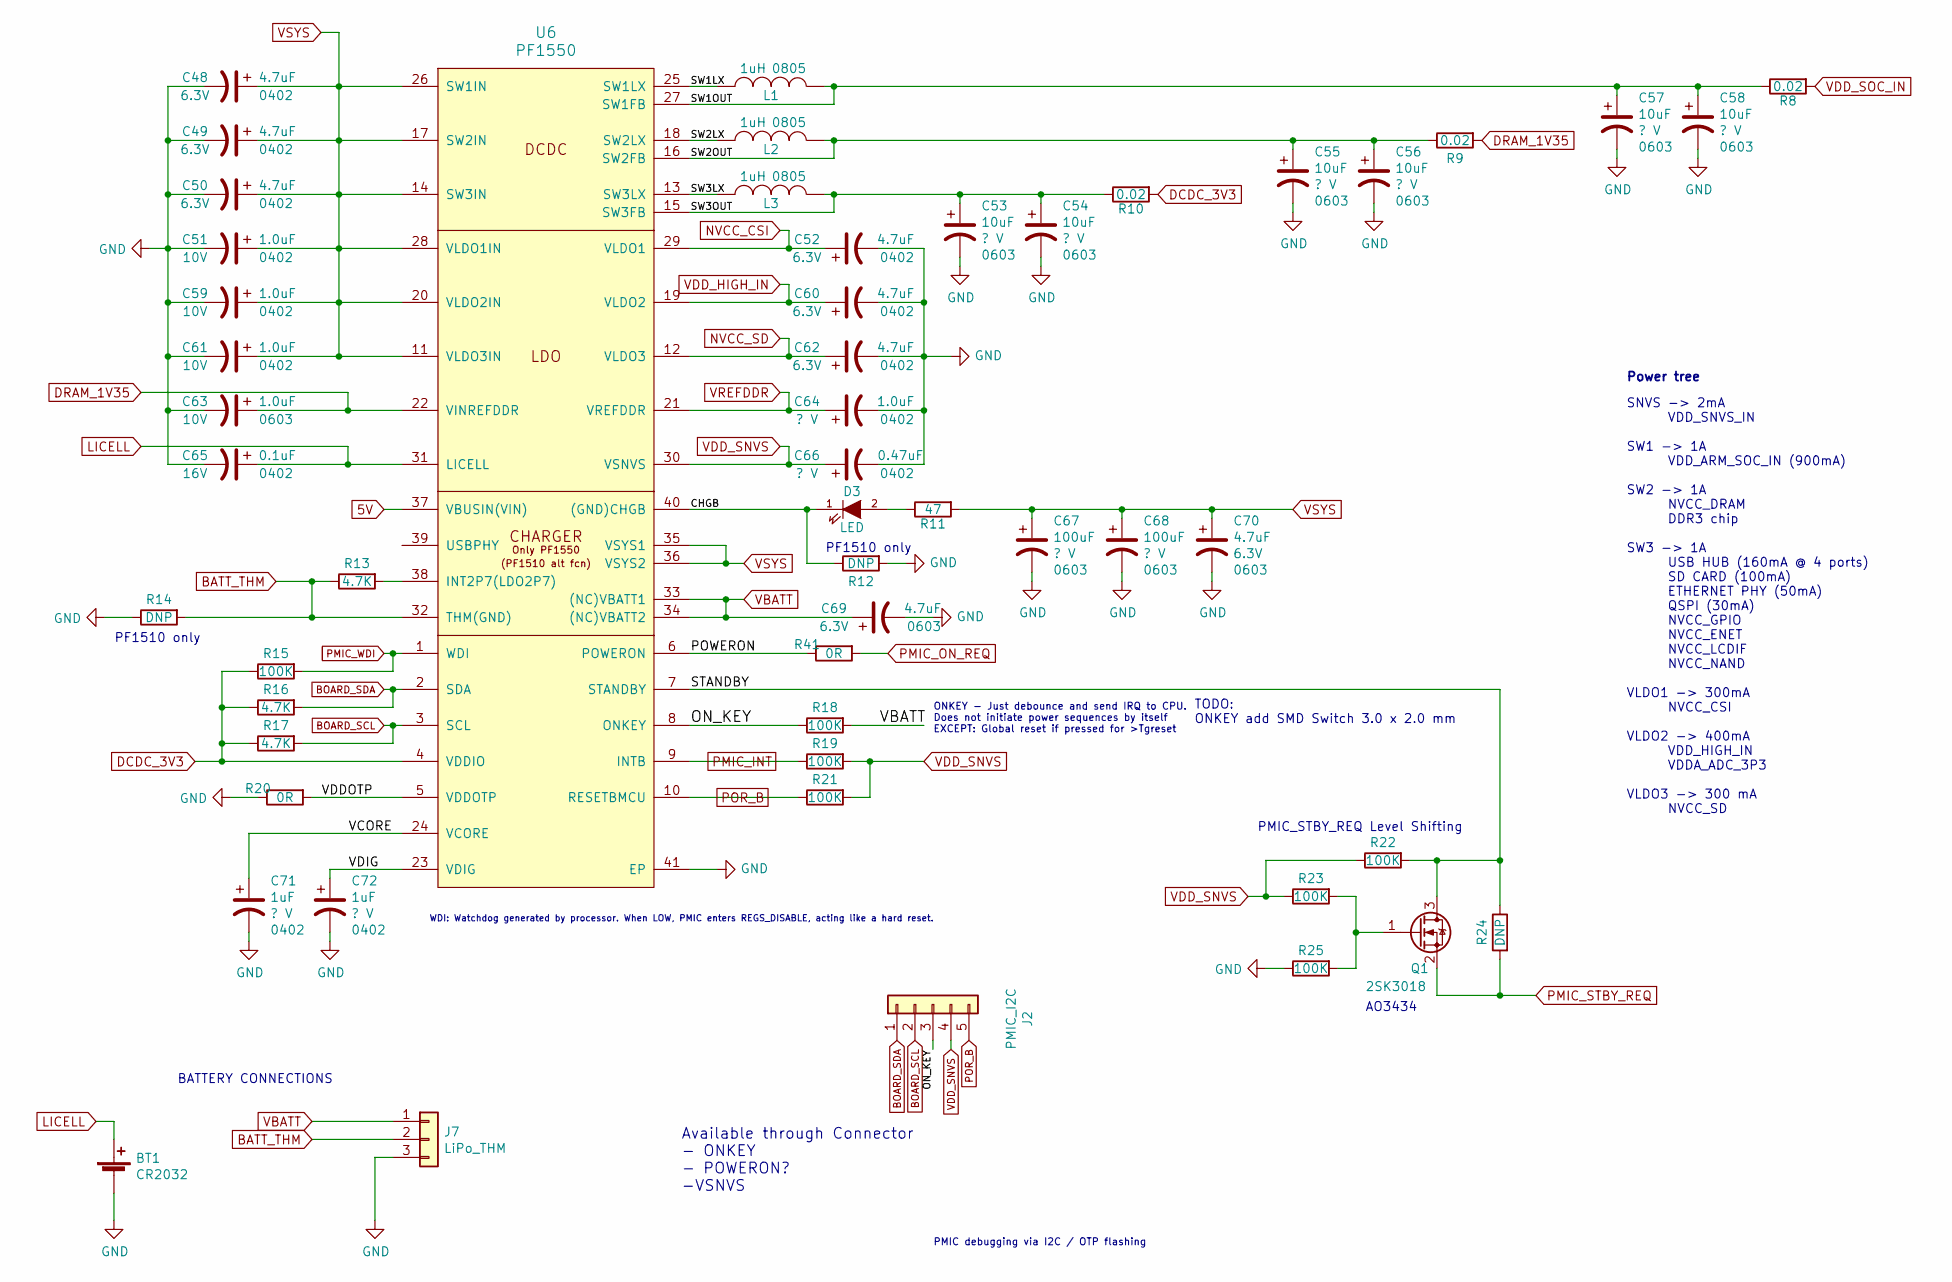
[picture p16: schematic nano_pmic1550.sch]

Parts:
BT1: CR2032; BatteryHolder_Keystone_1058_1x2032
C48, C49, C50, C52, C60, C62: 4.7uF; C_0402_narrow; Voltage 6.3V
C51, C59, C61: 1.0uF; C_0402_narrow; Voltage 10V
C53, C54, C55, C56, C57, C58: 10uF; C_0603_narrow; Voltage ? V
C63: 1.0uF; C_0603_narrow; Voltage 10V
C64: 1.0uF; C_0402_narrow; Voltage ? V
C65: 0.1uF; C_0603_narrow; Voltage 16V
C66: 0.47uF; C_0402_narrow; Voltage ? V
C67, C68: 100uF; C_0603_narrow; Voltage ? V
C69, C70: 4.7uF; C_0603_narrow; Voltage 6.3V
C71, C72: 1uF; C_0402_narrow; Voltage ? V
D3: LED; LED_0402_1005Metric
J2: PMIC_I2C; PinHeader_1x05_P2.54mm_Vertical
J7: LiPo_THM; PinHeader_1x03_P2.54mm_Vertical
L1, L2, L3: 1uH; L_0805_narrow
Q1: 2SK3018; SOT-23
R8, R9, R10: 0.02; R_0402_narrow
R11: 47; R_0402_narrow
R12, R14, R24: DNP; R_0402_narrow
R13, R16, R17: 4.7K; R_0402_narrow
R15, R18, R19, R21, R22, R23, R25: 100K; R_0402_narrow
R20, R41: 0R; R_0402_narrow
U6: PF1550; QFN-40-1EP_5x5mm_P0.4mm_EP3.6x3.6mm_ThermalVias

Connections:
5V: U6.37 (VBUSIN(VIN)); also elsewhere on the board
/PMIC PF1550/CHGB: D3.1 (K), R12.1, U6.40 ((GND)CHGB)
/PMIC PF1550/ON_KEY: J2.3, R18.1, U6.8 (ONKEY)
/PMIC PF1550/POWERON: R41.1, U6.6 (POWERON)
/PMIC PF1550/STANDBY: Q1.3 (D), R22.2, R24.1, U6.7 (STANDBY)
/PMIC PF1550/SW1LX: L1.2, U6.25 (SW1LX)
/PMIC PF1550/SW1OUT: C57.1, C58.1, L1.1, R8.1, U6.27 (SW1FB)
/PMIC PF1550/SW2LX: L2.2, U6.18 (SW2LX)
/PMIC PF1550/SW2OUT: C55.1, C56.1, L2.1, R9.1, U6.16 (SW2FB)
/PMIC PF1550/SW3LX: L3.2, U6.13 (SW3LX)
/PMIC PF1550/SW3OUT: C53.1, C54.1, L3.1, R10.1, U6.15 (SW3FB)
/PMIC PF1550/VCORE: C71.1, U6.24 (VCORE)
/PMIC PF1550/VDDOTP: R20.2, U6.5 (VDDOTP)
/PMIC PF1550/VDIG: C72.1, U6.23 (VDIG)
BATT_THM: J7.2, R13.1, R14.2, U6.32 (THM(GND))
BOARD_SCL: J2.2, R17.2, U6.3 (SCL); also elsewhere on the board
BOARD_SDA: J2.1, R16.2, U6.2 (SDA); also elsewhere on the board
DCDC_3V3: R10.2, R15.1, R16.1, R17.1, U6.4 (VDDIO); also elsewhere on the board
DRAM_1V35: C63.1, R9.2, U6.22 (VINREFDDR); also elsewhere on the board
GND: BT1.2 (-), C48.2, C49.2, C50.2, C51.2, C52.2, C53.2, C54.2, C55.2, C56.2, C57.2, C58.2, C59.2, C60.2, C61.2, C62.2, C63.2, C64.2, C65.2, C66.2, C67.2, C68.2, C69.2, C70.2, C71.2, C72.2, J7.3, R12.2, R14.1, R20.1, R25.1, U6.41 (EP); also elsewhere on the board
LICELL: BT1.1 (+), C65.1, U6.31 (LICELL)
NVCC_CSI: C52.1, U6.29 (VLDO1); also elsewhere on the board
NVCC_SD: C62.1, U6.12 (VLDO3); also elsewhere on the board
unnamed: D3.2 (A), R11.1
unnamed: Q1.1 (G), R23.2, R25.2
unnamed: R13.2, U6.38 (INT2P7(LDO2P7))
PMIC_INT: R19.1, U6.9 (INTB); also elsewhere on the board
PMIC_ON_REQ: R41.2; also elsewhere on the board
PMIC_STBY_REQ: Q1.2 (S), R24.2; also elsewhere on the board
PMIC_WDI: R15.2, U6.1 (WDI); also elsewhere on the board
POR_B: J2.5, R21.1, U6.10 (RESETBMCU); also elsewhere on the board
VBATT: C69.1, J7.1, R18.2, U6.33 ((NC)VBATT1), U6.34 ((NC)VBATT2); also elsewhere on the board
VDD_HIGH_IN: C60.1, U6.19 (VLDO2); also elsewhere on the board
VDD_SNVS: C66.1, J2.4, R19.2, R21.2, R22.1, R23.1, U6.30 (VSNVS); also elsewhere on the board
VDD_SOC_IN: R8.2; also elsewhere on the board
VREFDDR: C64.1, U6.21 (VREFDDR); also elsewhere on the board
VSYS: C48.1, C49.1, C50.1, C51.1, C59.1, C61.1, C67.1, C68.1, C70.1, R11.2, U6.11 (VLDO3IN), U6.14 (SW3IN), U6.17 (SW2IN), U6.20 (VLDO2IN), U6.26 (SW1IN), U6.28 (VLDO1IN), U6.35 (VSYS1), U6.36 (VSYS2)

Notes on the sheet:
Available through Connector - ONKEY - POWERON? -VSNVS
Power tree
SNVS -> 2mA VDD_SNVS_IN SW1 -> 1A VDD_ARM_SOC_IN (900mA) SW2 -> 1A NVCC_DRAM DDR3 chip SW3 -> 1A USB HUB (160mA @ 4 ports) SD CARD (100mA) ETHERNET PHY (50mA) QSPI (30mA) NVCC_GPIO NVCC_ENET NVCC_LCDIF NVCC_NAND VLDO1 -> 300mA NVCC_CSI VLDO2 -> 400mA VDD_HIGH_IN VDDA_ADC_3P3 VLDO3 -> 300 mA NVCC_SD
PF1510 only
PMIC debugging via I2C / OTP flashing
ONKEY - Just debounce and send IRQ to CPU. Does not initiate power sequences by itself EXCEPT: Global reset if pressed for >Tgreset
PMIC_STBY_REQ Level Shifting
AO3434
BATTERY CONNECTIONS
WDI: Watchdog generated by processor. When LOW, PMIC enters REGS_DISABLE, acting like a hard reset.
TODO: ONKEY add SMD Switch 3.0 x 2.0 mm

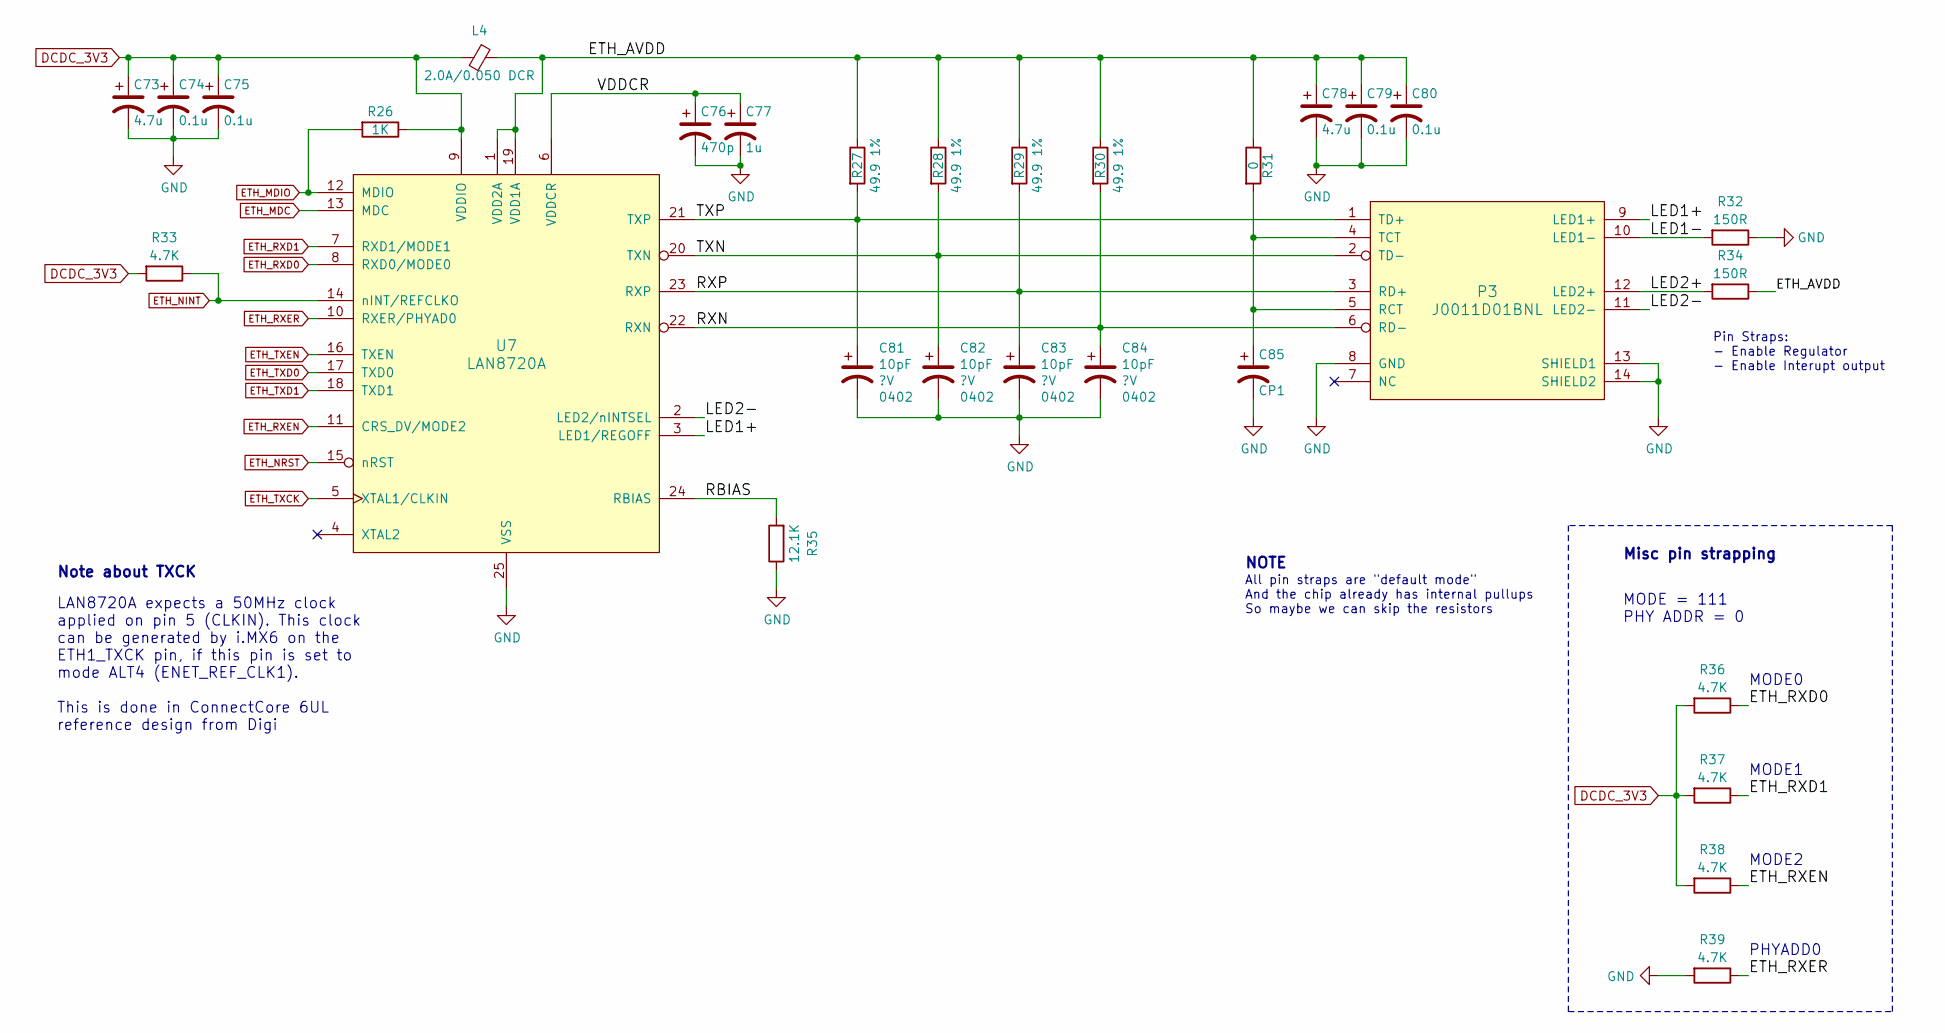
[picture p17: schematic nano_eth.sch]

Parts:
C73, C78: 4.7u; C_0603_narrow
C74, C75, C79, C80: 0.1u; C_0402_narrow
C76: 470p; C_0402_narrow
C77: 1u; C_0603_narrow
C81, C82, C83, C84: 10pF; C_0402_narrow; Voltage ?V
C85: CP1; C_0402_narrow
L4: 2.0A/0.050 DCR; R_0805_2012Metric
P3: J0011D01BNL; MTJ-88TX1-FSD-D1LH-M4Y
R26: 1K; R_0402_narrow
R27, R28, R29, R30: 49.9 1%; R_0402_narrow
R31: 0; R_0402_narrow
R32, R34: 150R; R_0402_narrow
R33, R36, R37, R38, R39: 4.7K; R_0402_narrow
R35: 12.1K; R_0402_narrow
U7: LAN8720A; QFN-24-1EP_4x4mm_P0.5mm_EP2.6x2.6mm_ThermalVias

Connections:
/ETHERNET/ETH_AVDD: C78.1, C79.1, C80.1, L4.1, R27.1, R28.1, R29.1, R30.1, R31.1, R34.1, U7.1 (VDD2A), U7.19 (VDD1A)
/ETHERNET/LED1+: P3.9 (LED1+), U7.3 (LED1/REGOFF)
/ETHERNET/LED1-: P3.10 (LED1-), R32.2
/ETHERNET/LED2+: P3.12 (LED2+), R34.2
/ETHERNET/LED2-: P3.11 (LED2-), U7.2 (LED2/nINTSEL)
/ETHERNET/RBIAS: R35.2, U7.24 (RBIAS)
/ETHERNET/RXN: C84.1, P3.6 (RD-), R30.2, U7.22 (RXN)
/ETHERNET/RXP: C83.1, P3.3 (RD+), R29.2, U7.23 (RXP)
/ETHERNET/TXN: C82.1, P3.2 (TD-), R28.2, U7.20 (TXN)
/ETHERNET/TXP: C81.1, P3.1 (TD+), R27.2, U7.21 (TXP)
/ETHERNET/VDDCR: C76.1, C77.1, U7.6 (VDDCR)
DCDC_3V3: C73.1, C74.1, C75.1, L4.2, R26.1, R33.2, R36.2, R37.2, R38.2, U7.9 (VDDIO); also elsewhere on the board
ETH_MDC: U7.13 (MDC); also elsewhere on the board
ETH_MDIO: R26.2, U7.12 (MDIO); also elsewhere on the board
ETH_NINT: R33.1, U7.14 (nINT/REFCLKO); also elsewhere on the board
ETH_NRST: U7.15 (nRST); also elsewhere on the board
ETH_RXD0: R36.1, U7.8 (RXD0/MODE0); also elsewhere on the board
ETH_RXD1: R37.1, U7.7 (RXD1/MODE1); also elsewhere on the board
ETH_RXEN: R38.1, U7.11 (CRS_DV/MODE2); also elsewhere on the board
ETH_RXER: R39.1, U7.10 (RXER/PHYAD0); also elsewhere on the board
ETH_TXCK: U7.5 (XTAL1/CLKIN); also elsewhere on the board
ETH_TXD0: U7.17 (TXD0); also elsewhere on the board
ETH_TXD1: U7.18 (TXD1); also elsewhere on the board
ETH_TXEN: U7.16 (TXEN); also elsewhere on the board
GND: C73.2, C74.2, C75.2, C76.2, C77.2, C78.2, C79.2, C80.2, C81.2, C82.2, C83.2, C84.2, C85.2, P3.8 (GND), P3.13 (SHIELD1), P3.14 (SHIELD2), R32.1, R35.1, R39.2, U7.25 (VSS); also elsewhere on the board
unnamed: C85.1, P3.4 (TCT), P3.5 (RCT), R31.2

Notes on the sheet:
Note about TXCK
LAN8720A expects a 50MHz clock applied on pin 5 (CLKIN). This clock can be generated by i.MX6 on the ETH1_TXCK pin, if this pin is set to mode ALT4 (ENET_REF_CLK1). This is done in ConnectCore 6UL reference design from Digi
PHYADD0
MODE0
MODE1
MODE2
MODE = 111 PHY ADDR = 0
Misc pin strapping
Pin Straps: - Enable Regulator - Enable Interupt output
NOTE
All pin straps are "default mode" And the chip already has internal pullups So maybe we can skip the resistors

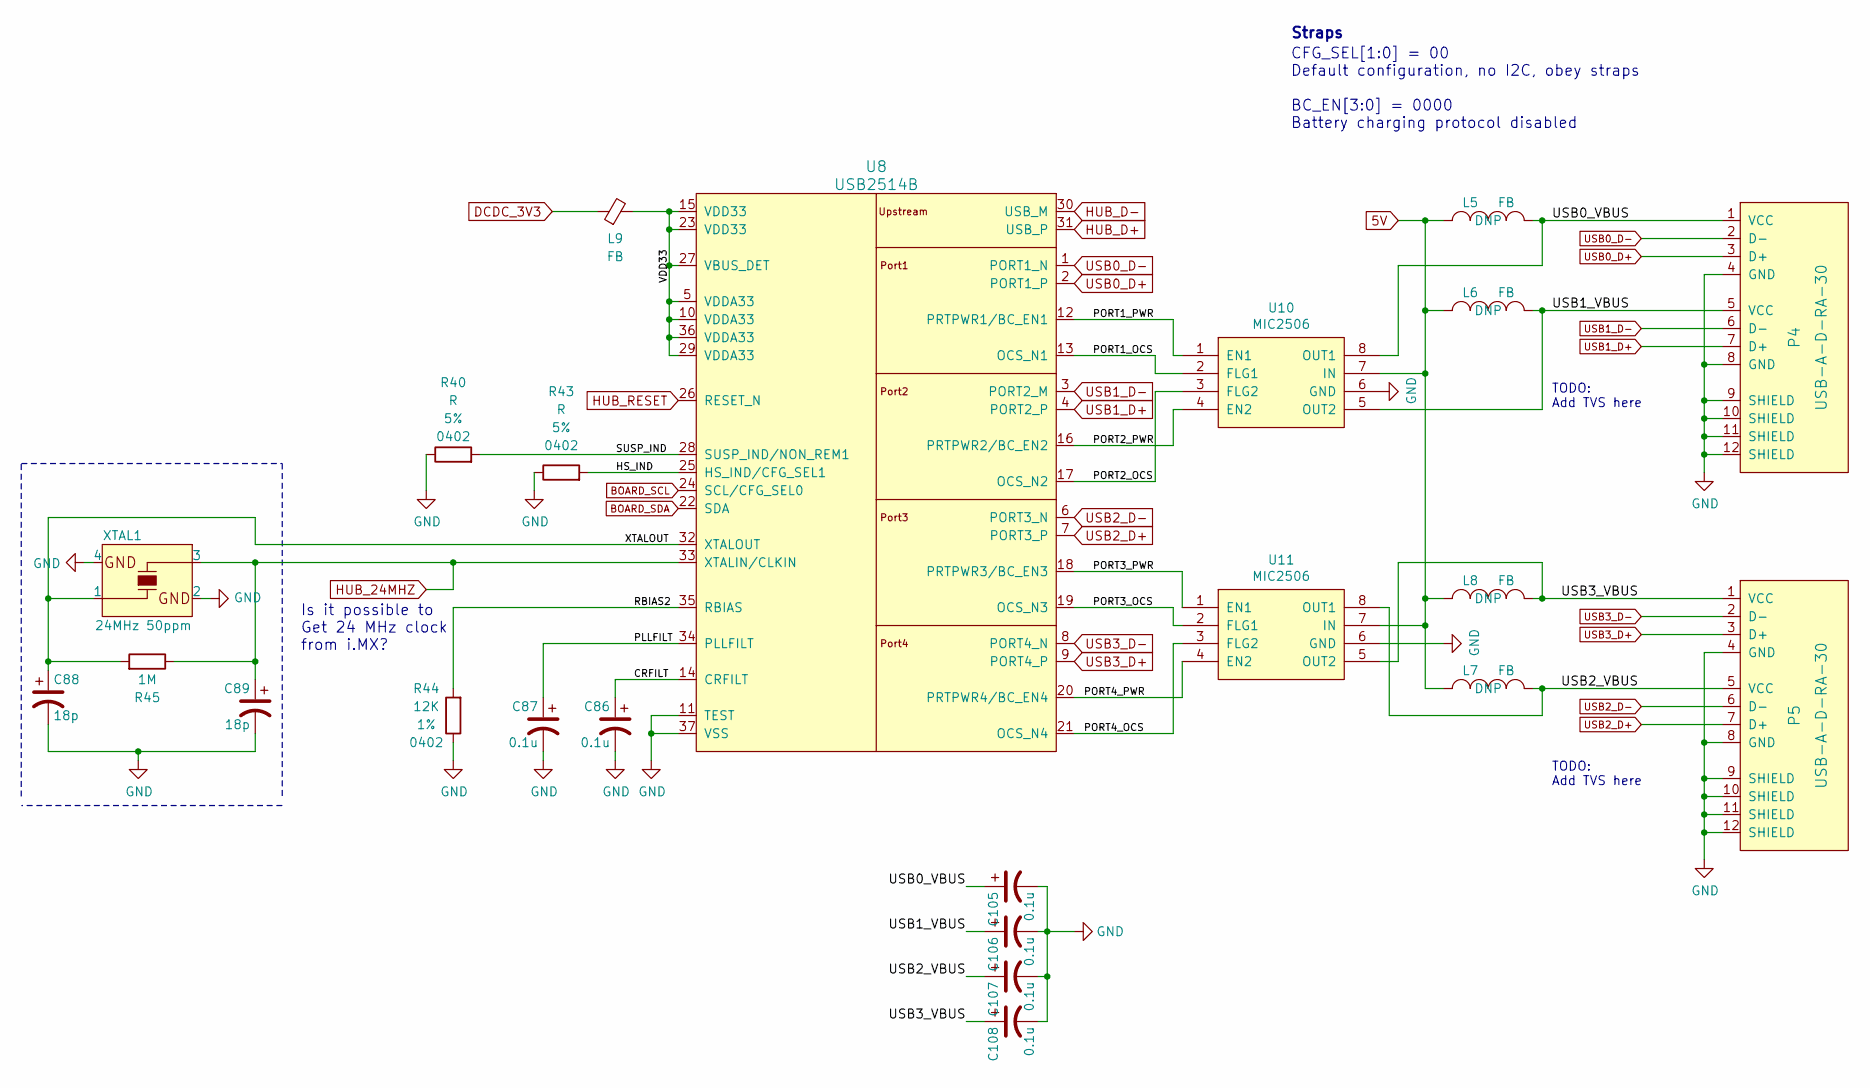
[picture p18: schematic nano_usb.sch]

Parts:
C86, C87, C105, C106, C107, C108: 0.1u; C_0402_narrow
C88, C89: 18p; C_0402_narrow
L5, L6, L7, L8, L9: FB; L_0805_narrow
P4, P5: USB-A-D-RA-30
R40, R43: R; R_0402_narrow; Tolerance 5%
R44: 12K; R_0402_narrow; Tolerance 1%
R45: 1M; R_0402_narrow
U8: USB2514B; QFN-36-1EP_6x6mm_P0.5mm_EP3.7x3.7mm_ThermalVias
U10, U11: MIC2506; SOIC-8_3.9x4.9mm_P1.27mm
XTAL1: 24MHz 50ppm; Oscillator_SMD_EuroQuartz_XO32-4Pin_3.2x2.5mm

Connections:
5V: L5.1, L6.1, L7.1, L8.1, U10.7 (IN), U11.7 (IN); also elsewhere on the board
/USB HUB/CRFILT: C86.1, U8.14 (CRFILT)
/USB HUB/HS_IND: R43.2, U8.25 (HS_IND/CFG_SEL1)
/USB HUB/PLLFILT: C87.1, U8.34 (PLLFILT)
/USB HUB/PORT1_OCS: U8.13 (OCS_N1), U10.2 (FLG1)
/USB HUB/PORT1_PWR: U8.12 (PRTPWR1/BC_EN1), U10.1 (EN1)
/USB HUB/PORT2_OCS: U8.17 (OCS_N2), U10.3 (FLG2)
/USB HUB/PORT2_PWR: U8.16 (PRTPWR2/BC_EN2), U10.4 (EN2)
/USB HUB/PORT3_OCS: U8.19 (OCS_N3), U11.2 (FLG1)
/USB HUB/PORT3_PWR: U8.18 (PRTPWR3/BC_EN3), U11.1 (EN1)
/USB HUB/PORT4_OCS: U8.21 (OCS_N4), U11.3 (FLG2)
/USB HUB/PORT4_PWR: U8.20 (PRTPWR4/BC_EN4), U11.4 (EN2)
/USB HUB/RBIAS2: R44.2, U8.35 (RBIAS)
/USB HUB/SUSP_IND: R40.2, U8.28 (SUSP_IND/NON_REM1)
/USB HUB/USB0_VBUS: C105.1, L5.2, P4.1 (VCC), U10.8 (OUT1)
/USB HUB/USB1_VBUS: C106.1, L6.2, P4.5 (VCC), U10.5 (OUT2)
/USB HUB/USB2_VBUS: C107.1, L7.2, P5.5 (VCC), U11.8 (OUT1)
/USB HUB/USB3_VBUS: C108.1, L8.2, P5.1 (VCC), U11.5 (OUT2)
/USB HUB/VDD33: L9.2, U8.5 (VDDA33), U8.10 (VDDA33), U8.15 (VDD33), U8.23 (VDD33), U8.27 (VBUS_DET), U8.29 (VDDA33), U8.36 (VDDA33)
/USB HUB/XTALOUT: C88.1, R45.2, U8.32 (XTALOUT), XTAL1.1
BOARD_SCL: U8.24 (SCL/CFG_SEL0); also elsewhere on the board
BOARD_SDA: U8.22 (SDA); also elsewhere on the board
DCDC_3V3: L9.1; also elsewhere on the board
GND: C86.2, C87.2, C88.2, C89.2, C105.2, C106.2, C107.2, C108.2, P4.4 (GND), P4.8 (GND), P4.9 (SHIELD), P4.10 (SHIELD), P4.11 (SHIELD), P4.12 (SHIELD), P5.4 (GND), P5.8 (GND), P5.9 (SHIELD), P5.10 (SHIELD), P5.11 (SHIELD), P5.12 (SHIELD), R40.1, R43.1, R44.1, U8.11 (TEST), U8.37 (VSS), U10.6 (GND), U11.6 (GND), XTAL1.2, XTAL1.4; also elsewhere on the board
HUB_24MHZ: C89.1, R45.1, U8.33 (XTALIN/CLKIN), XTAL1.3; also elsewhere on the board
HUB_D+: U8.31 (USB_P); also elsewhere on the board
HUB_D-: U8.30 (USB_M); also elsewhere on the board
HUB_RESET: U8.26 (RESET_N); also elsewhere on the board
USB0_D+: P4.3 (D+), U8.2 (PORT1_P)
USB0_D-: P4.2 (D-), U8.1 (PORT1_N)
USB1_D+: P4.7 (D+), U8.4 (PORT2_P)
USB1_D-: P4.6 (D-), U8.3 (PORT2_M)
USB2_D+: P5.7 (D+), U8.7 (PORT3_P)
USB2_D-: P5.6 (D-), U8.6 (PORT3_N)
USB3_D+: P5.3 (D+), U8.9 (PORT4_P)
USB3_D-: P5.2 (D-), U8.8 (PORT4_N)

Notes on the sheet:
Is it possible to Get 24 MHz clock from i.MX?
Straps
CFG_SEL[1:0] = 00 Default configuration, no I2C, obey straps BC_EN[3:0] = 0000 Battery charging protocol disabled
TODO: Add TVS here

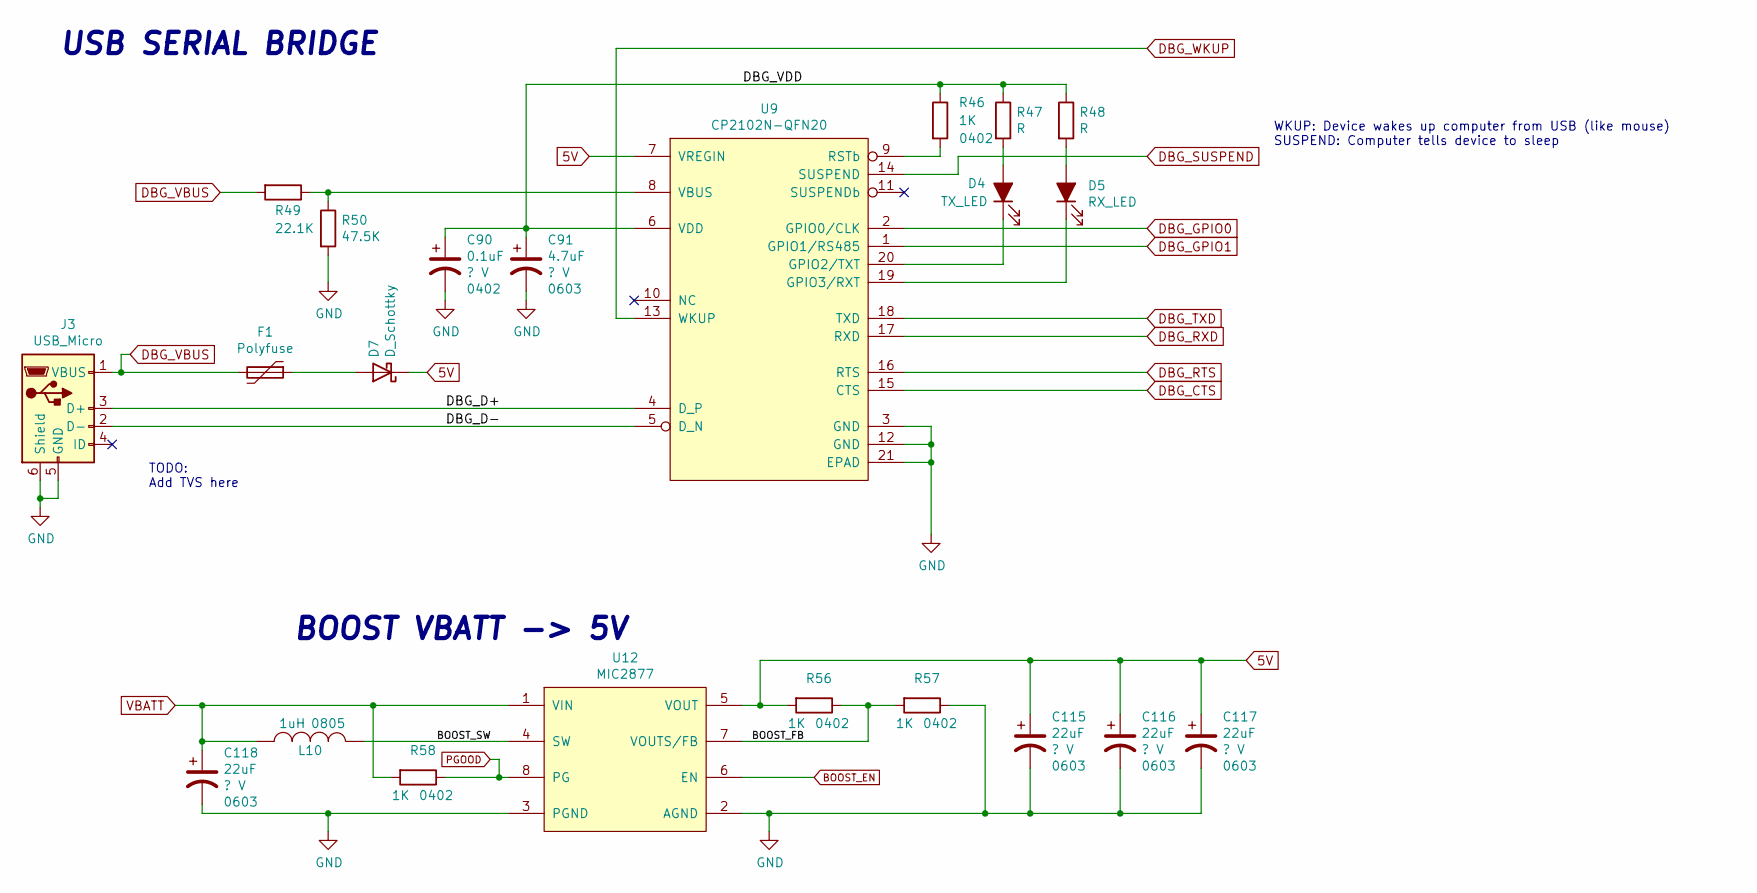
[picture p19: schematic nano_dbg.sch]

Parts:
C90: 0.1uF; C_0402_narrow; Voltage ? V
C91: 4.7uF; C_0603_narrow; Voltage ? V
C115, C116, C117, C118: 22uF; C_0603_narrow; Voltage ? V
D4: TX_LED; LED_0402_1005Metric
D5: RX_LED; LED_0402_1005Metric
D7: D_Schottky; D_0805_2012Metric
F1: Polyfuse; D_0805_2012Metric
J3: USB_Micro; MCR-B-S-RA-SMT-CS5
L10: 1uH; L_Bourns-SRN4018
R46, R56, R57, R58: 1K; R_0402_narrow
R47, R48: R; R_0402_narrow
R49: 22.1K; R_0402_narrow
R50: 47.5K; R_0402_narrow
U9: CP2102N-QFN20; SiliconLabs_QFN-20-1EP_3x3mm_CUSTOM
U12: MIC2877

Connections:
5V: C115.1, C116.1, C117.1, D7.1 (K), R56.2, U9.7 (VREGIN), U12.5 (VOUT); also elsewhere on the board
/USB DEBUG & OTG/BOOST_FB: R56.1, R57.2, U12.7 (VOUTS/FB)
/USB DEBUG & OTG/BOOST_SW: L10.1, U12.4 (SW)
/USB DEBUG & OTG/DBG_D+: J3.3 (D+), U9.4 (D_P)
/USB DEBUG & OTG/DBG_D-: J3.2 (D-), U9.5 (D_N)
/USB DEBUG & OTG/DBG_VDD: C90.1, C91.1, R46.1, R47.1, R48.1, U9.6 (VDD)
BOOST_EN: U12.6 (EN)
DBG_CTS: U9.15 (CTS); also elsewhere on the board
DBG_GPIO0: U9.2 (GPIO0/CLK); also elsewhere on the board
DBG_GPIO1: U9.1 (GPIO1/RS485); also elsewhere on the board
DBG_RTS: U9.16 (RTS); also elsewhere on the board
DBG_RXD: U9.17 (RXD); also elsewhere on the board
DBG_SUSPEND: U9.14 (SUSPEND); also elsewhere on the board
DBG_TXD: U9.18 (TXD); also elsewhere on the board
DBG_VBUS: F1.2, J3.1 (VBUS), R49.2
DBG_WKUP: U9.13 (WKUP); also elsewhere on the board
GND: C90.2, C91.2, C115.2, C116.2, C117.2, C118.2, J3.5 (GND), J3.6 (Shield), R50.2, R57.1, U9.3 (GND), U9.12 (GND), U9.21 (EPAD), U12.2 (AGND), U12.3 (PGND); also elsewhere on the board
unnamed: D4.1 (K), U9.20 (GPIO2/TXT)
unnamed: D4.2 (A), R47.2
unnamed: D5.1 (K), U9.19 (GPIO3/RXT)
unnamed: D5.2 (A), R48.2
unnamed: D7.2 (A), F1.1
unnamed: R46.2, U9.9 (RSTb)
unnamed: R49.1, R50.1, U9.8 (VBUS)
PGOOD: R58.1, U12.8 (PG)
VBATT: C118.1, L10.2, R58.2, U12.1 (VIN); also elsewhere on the board

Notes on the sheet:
WKUP: Device wakes up computer from USB (like mouse) SUSPEND: Computer tells device to sleep
TODO: Add TVS here
USB SERIAL BRIDGE
BOOST VBATT -> 5V

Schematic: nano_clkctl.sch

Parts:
C96, C97: 18p; C_0402_narrow
C98, C99: 18pF; C_0402_narrow; Voltage ?
C100: 0.1uF; C_0402_narrow; Voltage 25V
C101: 1.0uF; C_0402_narrow; Voltage 10V
FB1: Bead; R_0402_narrow
J5: JTAG; PinHeader_2x05_P1.00mm_Vertical_SMD
R52: 4.7k; R_0402_narrow
R53: 1M; R_0402_narrow; Tolerance ?
R54: 499; R_0402_narrow
R55: 2.2M; R_0402_narrow
SB1, SB2, SB3, SB4: 4.7K; R_0402_narrow; Tolerance ?
U1: IMX6UL_BGA289
XTAL2: 24MHz 50ppm; Oscillator_SMD_EuroQuartz_XO32-4Pin_3.2x2.5mm
Y1: 32.768 kHz; Crystal_SMD_3215-2Pin_3.2x1.5mm

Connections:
/Clock_and_Control/BOOT0: SB3.1, SB4.1, U1.T10 (BOOT_MODE0)
/Clock_and_Control/BOOT1: SB1.1, SB2.1, U1.U10 (BOOT_MODE1)
/Clock_and_Control/IMX_XTALI: C99.1, R53.1, R55.1, U1.T16 (XTALI), XTAL2.3
/Clock_and_Control/IMX_XTALO: C98.1, R53.2, R54.1, U1.T17 (XTALO), XTAL2.1
/Clock_and_Control/JTAG_MOD: R52.2, U1.P15 (JTAG_MOD)
/Clock_and_Control/JTAG_TCK: J5.4, U1.M14 (JTAG_TCK)
/Clock_and_Control/JTAG_TDI: J5.8, U1.N16 (JTAG_TDI)
/Clock_and_Control/JTAG_TDO: J5.6, U1.N15 (JTAG_TDO)
/Clock_and_Control/JTAG_TMS: J5.2, U1.P14 (JTAG_TMS)
/Clock_and_Control/JTAG_TRST_B: J5.7, U1.N14 (JTAG_TRST_B)
/Clock_and_Control/RTC_XTALI: C97.1, U1.T11 (RTC_XTALI), Y1.2
/Clock_and_Control/RTC_XTALO: C96.1, U1.U11 (RTC_XTALO), Y1.1
/Clock_and_Control/SNVS8: U1.N9 (SNVS_TAMPER8)
/Clock_and_Control/VDDA_ADC: C100.1, C101.1, FB1.2, U1.L13 (VDDA_ADC_3P3), U1.M13 (ADC_VREFH)
A71_NRST: U1.N8 (SNVS_TAMPER5); also elsewhere on the board
DCDC_3V3: J5.1; also elsewhere on the board
GND: C96.2, C97.2, C98.2, C99.2, C100.2, C101.2, J5.3, J5.5, J5.9, R52.1, R54.2, R55.2, SB2.2, SB4.2, U1.N7 (TEST_MODE), XTAL2.2, XTAL2.4; also elsewhere on the board
HUB_RESET: U1.N11 (SNVS_TAMPER6); also elsewhere on the board
PMIC_INT: U1.P11 (SNVS_TAMPER2); also elsewhere on the board
PMIC_ON_REQ: U1.T9 (SNVS_PMIC_ON_REQ); also elsewhere on the board
PMIC_STBY_REQ: U1.U9 (CCM_PMIC_STBY_REQ); also elsewhere on the board
PMIC_WDI: U1.N10 (SNVS_TAMPER7); also elsewhere on the board
POR_B: J5.10, U1.P8 (POR_B); also elsewhere on the board
SNVS0: U1.R10 (SNVS_TAMPER0); also elsewhere on the board
SNVS1: U1.R9 (SNVS_TAMPER1); also elsewhere on the board
SNVS3: U1.P10 (SNVS_TAMPER3); also elsewhere on the board
SNVS4: U1.P9 (SNVS_TAMPER4); also elsewhere on the board
VDD_HIGH_IN: FB1.1; also elsewhere on the board
VDD_SNVS: SB1.2, SB3.2; also elsewhere on the board

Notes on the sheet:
ONOFF - Not connected (controlled by PMIC) IMX6ULLRM Fig.51-2
POR_B - Open drain input controlled by PMIC
TRST is not used in std JTAG conn Standard use is key (missing pin)
No place on PCB
BOOT1 BOOT0 ------------ 0 0 0 1 1 0 1 1

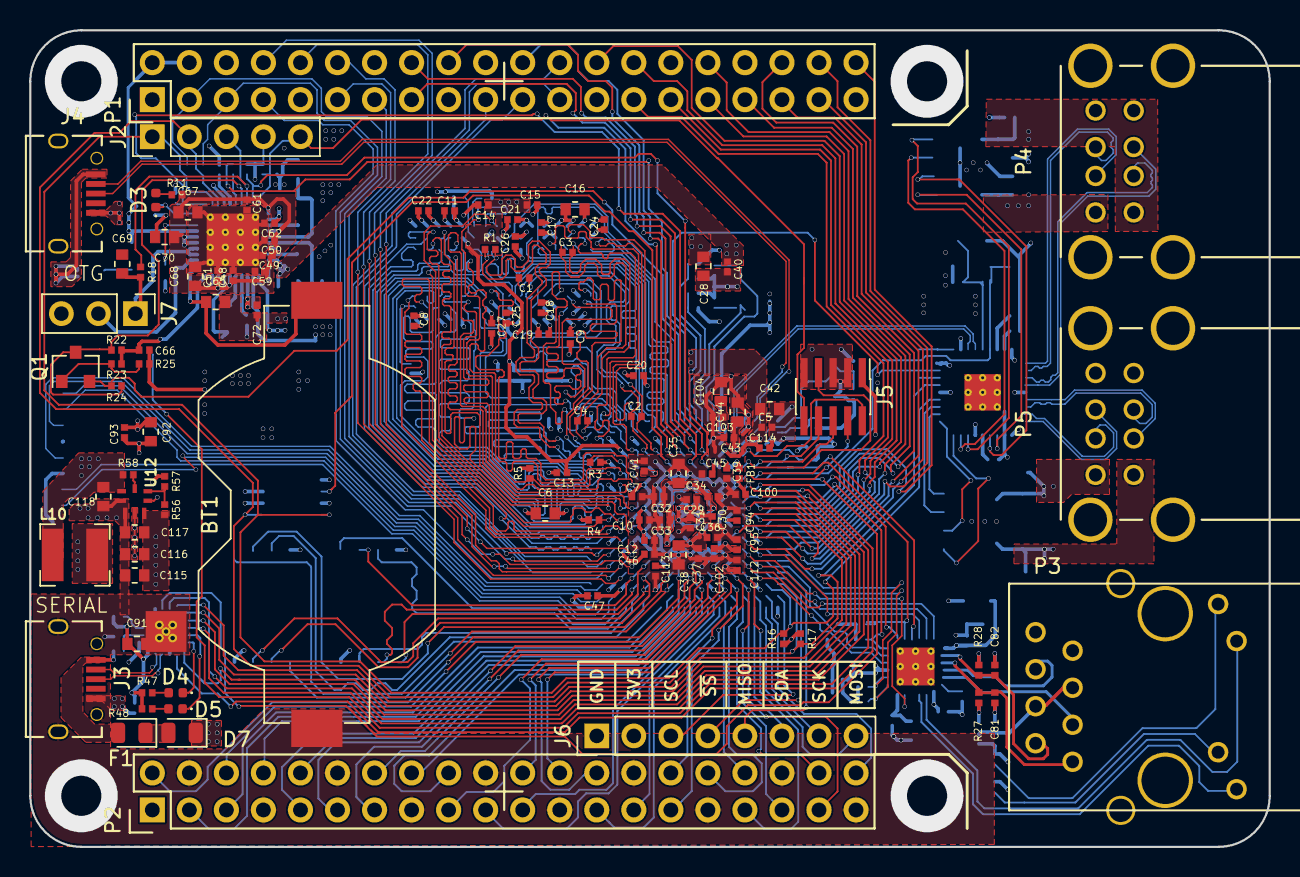
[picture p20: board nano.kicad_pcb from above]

Board: 4 copper layers, 85.0 x 56.0 mm, 229 parts (0 on the bottom side), 276 nets.

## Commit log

2020-05-19 uart2/3 layout
    [nano.kicad_pcb]
2020-05-19 layout: move jtag connector
    [nano.kicad_pcb]
2020-05-24 layout: move usb hub, improve gpio connections
    [nano.kicad_pcb, nano.sch, nano_clkctl.sch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]
2020-05-25 fix DRC
    [nano.kicad_pcb, nano_clkctl.sch]
2020-05-25 add block diagram
    [nano.kicad_pcb]
2020-06-11 layout improvement
    [nano.kicad_pcb]
2020-06-12 add i2c for ULZ
    [nano.kicad_pcb, periph1.sch]
2020-06-12 pmic_int connection
    [nano.kicad_pcb, nano_clkctl.sch, nano_dbg.sch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]
2020-06-12 remove vsnvs diodes
    [nano.kicad_pcb, nano_clkctl.sch, nano_power.sch]
